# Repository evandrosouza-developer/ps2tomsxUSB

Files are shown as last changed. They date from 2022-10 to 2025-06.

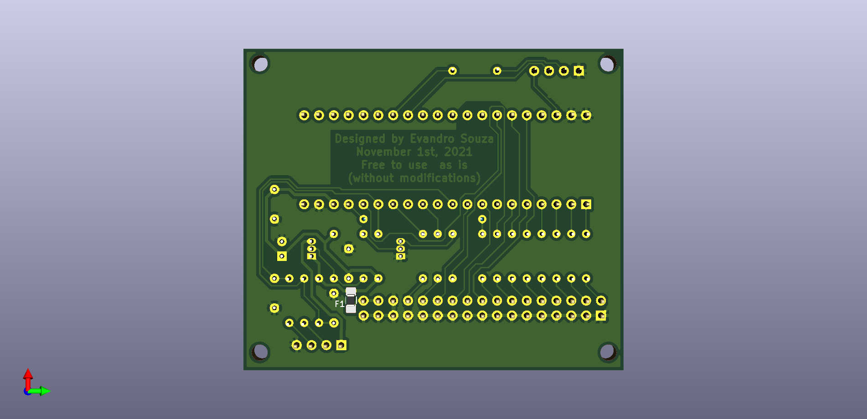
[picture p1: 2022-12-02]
Documentation/Kicad/F1/PS2-MSX-F1 Back View.png

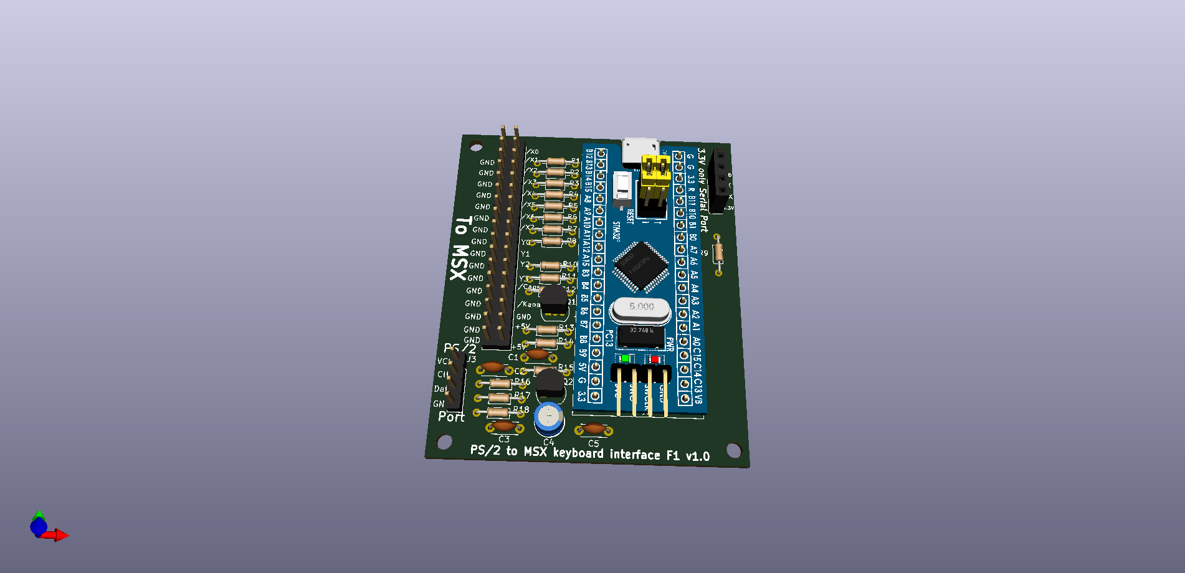
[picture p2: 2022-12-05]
Documentation/Kicad/F1/PS2-MSX-F1 Lower front.png

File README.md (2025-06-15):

# STM32: PS/2 to MSX Keyboard Converter

# Introduction

First of all, to people who use or had used MSX, welcome, bem-vindos, welkom, bienvenidos, добро пожаловать, 환영하다 and ようこそ, to visit my repository.

Instead of an application to this old japanese home computer standards is not so widely useful in nowadays, I made this to learn STM32 hardware and software technics, and I'd like it to be useful and let us back in time and make our MSX computer jewlers work with joyful to our pleasure.

The MSX Keyboard enviroment components (PS/2 to MSX Keyboard Converter, MSX Keyboard subsystem Emulator and the modifyed TIO - A simple terminal) are fully functional and debugged and here I used a lot of concepts that, IMHO could be used as idea sources to your applications.  

# Lets do it!

This interface has the function of connect a PS/2 keyboard (or a USB one in compatibility mode) as source to TTL zero (low state) active matrix based computers, like MSX and ZX-Spectrum as destination. It is meant to connect a keyboard, which only provides a PS/2 connector, to a MSX (or any one that have a up to 15 active columns and reads zeroes througth 8 bits - up to 15 x 8 matrix) computer.  

The differencial of this design is to allow user to customize and do a hot update of the database layout of this PS/2 Keyboard, as like as the MSX one, through an USB (or async serial) interface and a tty terminal on host side.  

The default database mappings for the keyboard layouts are:

- Source (PS/2 keyboard): 275 (ABNT2 layout - Brazilian Technical Norms Association);

- Target: Brazilian Sharp/Epcom Hotbit HB8000 MSX.  

This firmware was made to support both Blue Pill and Black Pill and it is part of the PS/2 to MSX Converter Enviroment, all of them in my github page, that consists:
```
1)The PS/2 to MSX Keyboard Converter itself, which contains:
1.1) The firmware with source files;
1.2) Doxygen full firmware documentation;
1.3) Schematics and PCB design:
1.3.1) Electronics part Schematics with Kicad files;
1.3.2) Single sided PCB layout with Kicad files and complete set of Gerber files;
1.4) The performance tests of this one are inside the PS/2 to MSX Converter Tester folder.

2)The PS/2 to MSX Converter Tester, which contains:
2.1) The firmware with source files;
2.2) Doxygen full firmware documentation;
2.3) Schematics design with Kicad files;
2.4) The performance tests of the PS/2 to MSX Keyboard Converter are located here.

3) Open tool to create/modify the Database (Translation tables to map from PS/2 Scan Codes to MSX Matrix Codes)
in excel, but it has compatible macros to be executed by Libre Office, Open Office and so on.

4) Tini TTY I/O - `tio` (Linux app with source files) to communicate with console and easily allowing the
user to use it with different keyboard layouts and languages.
```
In case of STM32F103C8T6 (Flash 64K RAM 20K) Blue Pill, you have to aplly STM32F103C6T6 (Flash 32K RAM 10K) without change anything else.

In case of Black Pill, the base system is STM32F401CCU6 so, to use a more memory one, just follow the same instructions here.

This firmware powers and has been tested on the following Windows PS/2 keyboards, with brazilian 275 layout:  
- Compaq RT235BTWBR;  
- Clone KE11090749;  
- Clone #09100.  
  
The inspiring code for the PS/2 module, a PS/2 to USB keyboard adapter, was originally developed based on Cherry G80-3000LSMDE.  

# Why not STM32F103C8T6 Blue Pill?

Because Blue Pill has no 5V tolerant pins available to connect PS/2 + MSX + Serial + USB, unlike Black Pill. Even serial (UART) was feasibled using a 3.3V only port.  
Although, this limitation came with a bonus: The need of a cheaper and greater availability 32KB flash MCU: STM32F103C6T6  

# Dependencies

- `libopencm3`
- `arm-none-eabi-gcc`
- `arm-none-eabi-binutils`

If you plan to debug:
- `arm-none-eabi-gdb`
- `stlink + openocd`

Obs.: If you plan to keep only one copy of LibopenCM3 in your computer, I strongly suggest you to setup the variable OPENCM3_DIR in our system enviroment.

# Preparations

After cloning the repository you need to make the following procedure:

Go to libopencm3 you cloned (eg: cd libopencm3) and make it to be useful by typing:

```
cd libopencm3
make TARGETS='stm32/f1 stm32/f4'
```

Go to this ps2-msx-kb-conv (PS/2 to MSX Converter) project folder and assure that you choose the right target MCU in the system.h file line 69, and make, as follows:

With a plain text editor:
```
#define MCU                       STM32F401
or
#define MCU                       STM32F103
```

Save the file, and,  
Create the image file to be sent to the MCU (Micro Controller Unit):

```
make
```
The created image, compiled with the Arm GNU Toolchain 14.2.Rel1 Released: December 10, 2024, on an aarch64 debian bullseye linux computer is created with the following characteristics, according to the choosen MCU:
```
arm-none-eabi-size ps2-msx-kb-convF4.elf
   text	   data	    bss	    dec	    hex	filename
35796	    384	   8436	  44616	   ae48	ps2-msx-kb-convF4.elf

arm-none-eabi-size ps2-msx-kb-convF1.elf
   text	   data	    bss	    dec	    hex	filename
  27152	    352	   2492	  29996	   752c	ps2-msx-kb-convF1.elf

```

# Hardware and Setup

## Hardware and Setup for Blue Pill:

You will obviously need a STM32F103C6T6 or a STM32F103C8T6 (F1 chip). I have used chinese blue pills. The software was made aiming in use of compatible processors, like GD32 for example. 
  
The software was made considering 8.000Mhz oscillator crystal, to clock the STM32 microcontroller chip at 72MHz. I tested with both STM32F103C6T6 and STM32F103C8T6.

The connections are:

1) PS/2 Keyboard:

- Clock Pin PA12 - Connect to PS/2 mini-din 45322 pin 5 throught R16;  
- Data Pin PA9 - Connect to PS/2 mini-din pin 1 throught R18;    
- +5V PS/2 power - Connect collector of Q2 to mini-din pin 4;  
- GND - Connect GNDD (Digital Ground) to mini-din pin 3.

2) MSX computer:

Obs.: You have to access PPI Ports B0 to B7 (Lines X0 to X7), Port C0 to C3 (Y0 to Y3), Port C6 (Caps Lock, pin 11 of DIP package), and for Russian, Arabic, Korean and Japanese Computers (Cyrillic and Kana alphabets), you have to get access to YM2149/AY3-8910 IOB7, pin 6 of DIP package, or, if your MSX is equipped with S1985(MSX-SYSTEM II), you have to have granted access to pins 71 and 72.  
- Y3 - Connect to MSX PPI 8255 Signal PC3 (HB-8000 CI-15 Pin 17 / XP-800 CI-4 Pin 17);  
- Y2 - Connect to MSX PPI 8255 Signal PC2 (HB-8000 CI-15 Pin 16 / XP-800 CI-4 Pin 16);  
- Y1 - Connect to MSX PPI 8255 Signal PC1 (HB-8000 CI-15 Pin 15 / XP-800 CI-4 Pin 15);  
- Y0 - Connect to MSX PPI 8255 Signal PC0 (HB-8000 CI-15 Pin 14 / XP-800 CI-4 Pin 14);  
- X7 - Connect to MSX PPI 8255 Signal PB7 (HB-8000 CI-15 Pin 25 / XP-800 CI-4 Pin 25);  
- X6 - Connect to MSX PPI 8255 Signal PB6 (HB-8000 CI-15 Pin 24 / XP-800 CI-4 Pin 24);  
- X5 - Connect to MSX PPI 8255 Signal PB5 (HB-8000 CI-15 Pin 23 / XP-800 CI-4 Pin 23);  
- X4 - Connect to MSX PPI 8255 Signal PB4 (HB-8000 CI-15 Pin 22 / XP-800 CI-4 Pin 22);  
- X3 - Connect to MSX PPI 8255 Signal PB3 (HB-8000 CI-15 Pin 21 / XP-800 CI-4 Pin 21);  
- X2 - Connect to MSX PPI 8255 Signal PB2 (HB-8000 CI-15 Pin 20 / XP-800 CI-4 Pin 20);  
- X1 - Connect to MSX PPI 8255 Signal PB1 (HB-8000 CI-15 Pin 19 / XP-800 CI-4 Pin 19);  
- X0 - Connect to MSX PPI 8255 Signal PB0 (HB-8000 CI-15 Pin 18 / XP-800 CI-4 Pin 18);  
- Caps LED - Connect to MSX PPI 8255 Signal PC6 (HB-8000 CI-15 Pin 11 / XP-800 CI-4 Pin 11) or S1985 Pin 71;  
- Kana LED - Connect to MSX YM2149 or AY3-8910 IOB7, pin 6 of DIP package or S1985 Pin 72. If the MSX doesn't have this indicator LED, you can leave it open, as it already has an internal pull-up connection. In brazilian, argentinian and most european MSX, for example, this is a non-connect pin.   

3) Serial console:
 It is the only option for console available if you are using Blue Pill. See "Why not STM32F103C8T6 Blue Pill?".

  The connection is needed only to update internal PS/2 to MSX key mapping Database.  
  Config: 115200, 8, n, 1 (115200 bps, 8 bits, no parity, 1 stop bit);  
  Tx: A2  
  Rx: A3  

  *******************************************************************************************************

  Obs.: It is a only 3.3V port, compatible to TTL levels, so do NOT use it with "1" level higher than 3.3V!!

  *******************************************************************************************************

 About physical connection: The connection has to be done with TX of your host system connected with RX of the PS/2 to MSX Keyboard Converter (device), and the device's TX has to be connected to host's RX.

## Hardware and Setup for Black Pill:

You will obviously need a a F4 chip (STM32F401CCU6 or up, if using WeAct Mini F4 compatible black pill).

The software was made considering 25.000Mhz oscillator crystal, to clock the STM32 microcontroller chip at 84MHz. I tested with both STM32F401CCU6 and STM32F401CDU6.

The connections are:

1) PS/2 Keyboard (J3- PS/2 Port) :

- PS/2 power - Pin 1 - Connect to PS/2 mini-din 45322 pin 4;  
- Clock      - Pin 2 - Connect to PS/2 mini-din 45322 pin 5;  
- Data       - Pin 3 - Connect to PS/2 mini-din 45322 pin 1;  
- GNDD       - Pin 4 - Connect to PS/2 mini-din 45322 pin 3.  

2) MSX computer:

Obs.: You have to access PPI Ports B0 to B7 (Lines X0 to X7), Port C0 to C3 (Y0 to Y3), Port C6 (Caps Lock, pin 11 of DIP package), and for Russian and Japanese Computers (Cyrillic and Kana alphabets), you have to get access to YM2149/AY3-8910 IOB7, pin 6 of DIP package, or, if your MSX is equipped with S1985(MSX-SYSTEM II), you have to have granted access to pins 71 and 72.  

- Y3 - Connect to MSX PPI 8255 Signal PC3 (HB-8000 CI-15 Pin 17 / XP-800 CI-4 Pin 17);  
- Y2 - Connect to MSX PPI 8255 Signal PC2 (HB-8000 CI-15 Pin 16 / XP-800 CI-4 Pin 16);  
- Y1 - Connect to MSX PPI 8255 Signal PC1 (HB-8000 CI-15 Pin 15 / XP-800 CI-4 Pin 15);  
- Y0 - Connect to MSX PPI 8255 Signal PC0 (HB-8000 CI-15 Pin 14 / XP-800 CI-4 Pin 14);  
- X7 - Connect to MSX PPI 8255 Signal PB7 (HB-8000 CI-15 Pin 25 / XP-800 CI-4 Pin 25);  
- X6 - Connect to MSX PPI 8255 Signal PB6 (HB-8000 CI-15 Pin 24 / XP-800 CI-4 Pin 24);  
- X5 - Connect to MSX PPI 8255 Signal PB5 (HB-8000 CI-15 Pin 23 / XP-800 CI-4 Pin 23);  
- X4 - Connect to MSX PPI 8255 Signal PB4 (HB-8000 CI-15 Pin 22 / XP-800 CI-4 Pin 22);  
- X3 - Connect to MSX PPI 8255 Signal PB3 (HB-8000 CI-15 Pin 21 / XP-800 CI-4 Pin 21);  
- X2 - Connect to MSX PPI 8255 Signal PB2 (HB-8000 CI-15 Pin 20 / XP-800 CI-4 Pin 20);  
- X1 - Connect to MSX PPI 8255 Signal PB1 (HB-8000 CI-15 Pin 19 / XP-800 CI-4 Pin 19);  
- X0 - Connect to MSX PPI 8255 Signal PB0 (HB-8000 CI-15 Pin 18 / XP-800 CI-4 Pin 18);  
- Caps LED - Connect to MSX PPI 8255 Signal PC6 (HB-8000 CI-15 Pin 11 / XP-800 CI-4 Pin 11) or S1985 Pin 71;  
- Kana LED - Connect to MSX YM2149 or AY3-8910 IOB7, pin 6 of DIP package or S1985 Pin 72. If the MSX doesn't have this indicator LED, you can leave it open, as it already has an internal pull-up connection. In brazilian, argentinian and most european MSX, for example, this is a non-connect pin.   
  
3) USB Type C: Needed only to update internal PS/2 to MSX key mapping Database. To create this Intel Hex file, better to use the Macro based Excel file, so you have to trust and enable macro excecution in excel app. The USB cable is the same as you use with yor mobile phone (USB Type-A Male x USB Type C Male).  
  
4) Serial console: Same observations of USB are applicable here, with exception of the cable itself. Here the connection has to be done with TX of your host system connected with RX of the PS/2 to MSX Keyboard Converter (device), and the device's TX has to be connected to host's RX.  
   Config: 115200, 8, n, 1 (115200 bps, 8 bits, no parity, 1 stop bit);  
   Tx: A9  
   Rx: A10  

  *******************************************************************************************************

  Obs.: It uses a 5V tolerant port, which is compatible to TTL levels, so do NOT use it with "1" level higher than 5V!!

  *******************************************************************************************************  

# The Database structure: Keyboard from/to mapping

This design was developed to connect, as default, an ABNT-2 brazilian PC keyboard to the brazilian MSX Sharp/Epcom HB-8000, but it is very easy to apply a hot change of its mapping:

- You have to compile and upload this new database to the Converter. This task is easily managed with the help of a Database compiler: The macro enabled excel file named `PS2toMSX_Database_Compiler.xlsm`.

To edit and compile the Database file, both source and target keyboard layouts, I prepaired a dedicated "key assembler in excel", so I can boldly recommend you to use the excel file `PS2toMSX_Database_Compiler.xlsm` available at github page.  
The Database Compiler file has 3 sheets: One for HB-8000, the second as XP-800 and the third one as an International MSX. Unfortunately, the last one was not tested. Just fillin the table, click on the keyboard image of upper left of the current sheet and wait for VBA has been concluded.  
The Database Compiler excel file exports the IHD.hex file (Intel Hex Database) to be hot applyed to PS/2 to MSX Keyboard Converter's Console, when this one boots up with no PS/2 Keyboard pluged in. Just follow console instructions. You may use `tio` as a terminal linux app to upload it.  
 
*******************************************************************  
<div align= "center"><strong>IMPORTANT</strong>  </div> 
<div align="left">If you are using Blackpill board and are uploading Database through USB, please do a FULL DISCONNECT (ALL lines INCUDING POWER) from MSX,  to avoid short circuit through power supply lines!  

I strongly suggest that the Black Pill board be pulled out from PS/2 to MSX Keyboard Converter board, as the power is going to be supplyed from USB and the heavy task to reconnect all will be saved, if you decided not to use the connector on the J1, which would simplify and make the task much safer.

*******************************************************************  

## Technical details about the Database structure

	There are 320 lines, so this structure is capable of manage up to 159 PS/2 keys, each key with make and break codes.

	The first and last lines are reserved for control (Database version, Database unavailable: seek next, double consistensy check, among others);
	
	On the first line there are information related to this Database version:
	- Bytes 0, 1 and 2: Database version ("0x01", "0x00", "0xFF")
	- Byte 3: Mapped function. Description:  
	  |  (bits 7-6): Reserved - keep it at high state;  
	  |  (bit 5): default value of enable_xon_xoff (true to enable it);  
	  |  (bit 4): default value of ps2numlockstate at power up (true to enable it);  
	  |  (bits 3-0): y_dummy (non valid colunm) - default value is 15 (0b1111);  
	- Bytes 4-7: Reserved - Keep it as 0xFFFFFFFF;
        When this copy of the Database is let unavailable, the first line becomes ("0x00", "0x00", "0x00", "0x00", "0x01", "0x02", 
	"0x04", "0x08"), meaning to seek the next one.

	On the line 319 (the last one) there are information related to this Database integrity:  
	- Bytes 0-5: Reserved - Keep each byte as 0xFF;  
	- Byte 6: CheckSum (Integrity);  
	- Byte 7: bcc (a vertical parity used for integrity);  

	Line 1 starts the raw of the Database:  
  
	The three first columns of each line are the mapped PS/2 scan codes;  
  
	The 4th column is The Control Byte, detailed bellow:   
	CONTROL BYTE:  
	- High nibble is Reserved;  
	- (bit 3) Combined Shift;  
	- (bit 2) Reserved-Not used;  
	- (bits 1-0) Modifyer Type:  
	  |		0 - Default mapping  
	  |		1 - NumLock Status+Shift changes  
	  |		2 - PS/2 Shift  
	  |		3 - Reserved-Not used  

	This table has 3 modifyers: Up two MSX keys are considered to each mapping behavior modifying:
	- 5th and 6th columns have the mapping 0 - "Default mapping";  
	- 7th and 8th columns share mappings:  1 and 2:  
	  |                                    1 - "NumLock Status+Shift changes";  
	  |                                    2 - "PS/2 Shift", where I need to release the sinalized Shift in PS/2 to the MSX and put the code key, and so, release them, reapplying the Shift key, deppending on the initial state;  

	Each column has a MSX encoded key, with the following structure:
	- (bits 7-4) MSX Y PPI 8255 PC3-0 is sent to a BCD decoder with OC outputs, for example:  
	  |	In the case of Hotbit HB8000, the keyboard scan is done as a 9 columns scan, CI-16 7445N 08 to 00;  
	  |	If equals to value stored at bits 3-0 of byte 3 of the Database file, there is no MSX key mapped.  
	- (bit 3) => 0: keypress / 1: key release;             
	- (bits 2-0) MSX X, ie, which bit of the PPI 8255 PB7-0 will carry information of bit 3 (keypress/key release).  

# Download your code to hardware

Use a ST-Link v2 Programmer (or similar), Black Magic Probe or another Serial Wire supported tool to flash the program using `make flash` onto the STM32.

If you choose a Black Pill, even you don't have plans to develop, you earn a bonus: you will not have the need of a dedicated programmer like ST-Link, J-link or Black Magic Probe to download your code, as STM32F4x1 MiniF4 already comes with DFU (Device Firmware Upgrade) available in the system ROM to do so through USB. So, on linux, just follow these steps:

1) Unplug the MSX connection or take off the Black Pill from the PS/2 to MSX Converter Main Board;  
2) Install dfu-util. This example is for Debian derivated Linux (Debian, Ubuntu, Mint, etc):
`sudo apt install dfu-util`  
3) Make sure the chip is at least 25°C (you may let it working for a while and help with the heat of your finger), because it uses internal oscillator to clock USB, factory trimmed to 25°C;  
4) Plug the USB cable to your computer and the STM32F4 board while holding both NRST and BOOT0;  
5) Then release BOOT0 AFTER 0.5 second you released NRST;  
6) Now you can see a new USB device in your linux enviroment, through `lsusb` command: 0483:df11. Run the command to flash the code itself:
`dfu-util -d 0483:df11 -a 0 -s 0x08000000 -D ps2-msx-kb-convF4.bin`  
7) Unplug the USB cable, undo the step 1 and power on the device to run the code.  
  
On windows you can download STM32CubeProg on ST site, replacing step 2. You have to adjust step 6 to this tool. Please follow ST instructions.

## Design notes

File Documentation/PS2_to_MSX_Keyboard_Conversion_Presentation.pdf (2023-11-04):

PPT模板下载：www.1ppt.com/moban/ 行业PPT模板：www.1ppt.com/hangye/ 节日PPT模板：www.1ppt.com/jieri/ PPT素材下载：www.1ppt.com/sucai/ PPT背景图片：www.1ppt.com/beijing/ PPT图表下载：www.1ppt.com/tubiao/
优秀PPT下载：www.1ppt.com/xiazai/ | PPT教程： www.1ppt.com/powerpoint/
Word教程： www.1ppt.com/word/ | Excel教程：www.1ppt.com/excel/
资料下载：www.1ppt.com/ziliao/
PPT课件下载：www.1ppt.com/kejian/
范文下载：www.1ppt.com/fanwen/

# PS/2 Keyboard for MSX And Legacy computers

## Evandro Souza <evandro.r.souza@gmail.com

## Based on: . ARM Cortex M3 Blue Pill stm32f103c6t6 . ARM Cortex M4 Black Pill stm32f401ccu6

# Introduction

## The main objective was to learn to use the ARM Core M3 and M4 Open Develop

Enviroment (free EDA, software tools and libraries).

## To do so, I chose a critic mission challenge, with implementation features not

## available in various smart solutions, as an example, the update translation

## database tables are not possible without full firmware recompilation and upload

## to hardware. In this one, a new database can be assembled and easily hot

upgradeable by the user through USB or serial port any times the user needs it.

## Show up a complete product design with full open documentation: Hardware

## (schematics plus PCB with gerber files, to ordering from PCB manufacturers) &

## Software (sources and its documentation), in order to allow to put this one into

production and get it maintained and supported.

Show up a simple and low cost solution to implement.

# Index

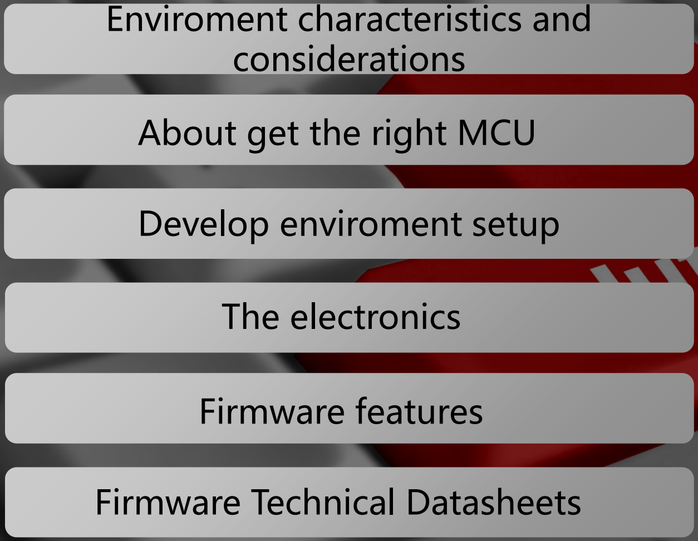
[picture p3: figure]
Enviroment characteristics and considerations; About get the right MCU; Develop enviroment setup; The electronics; Firmware features; Firmware Technical Datasheets

# Now

# Enviroment characteristics and

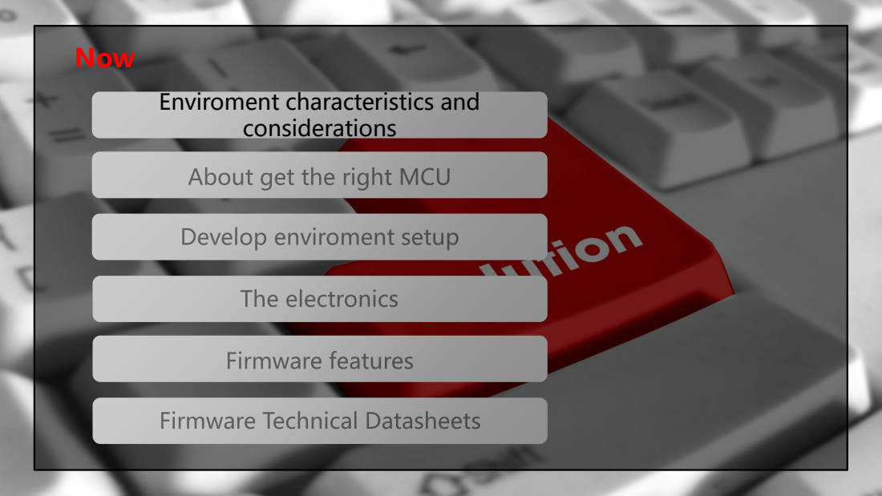
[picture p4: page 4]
considerations

# How MSX works (1/2)

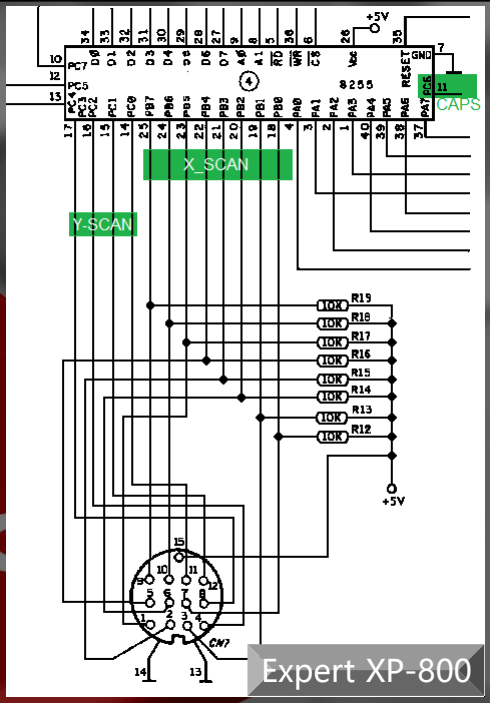
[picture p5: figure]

The MSX keyboard is a 8 lines (X) by up to 15 colunms (Y) matrix, which can achieve a theoretical maximum of 120 keys – The HB8000 has 9 columns, as seen on the example (J25 is the keyboard conector and, on left, its key mapping table). A highend japanese MSX uses a 11 colunms keyboard;
Firstly, the scan is done by writing on Y3:0 (PC3:0, address 0AAH), which goes to a decoder (up to) 4x16 with open-collector outputs, and reading from X7:0 (through PPI 8255 PB7:0, port 0A9H); The Caps Lock and Katakana states (“0”active ) are sampled directly from MSX hardware and echoed on PS/2 keyboard LEDs.
Sharp HB-8000 | Expert XP-800 X_SCAN Y_SCAN | CAPS

# How MSX works (2/2)

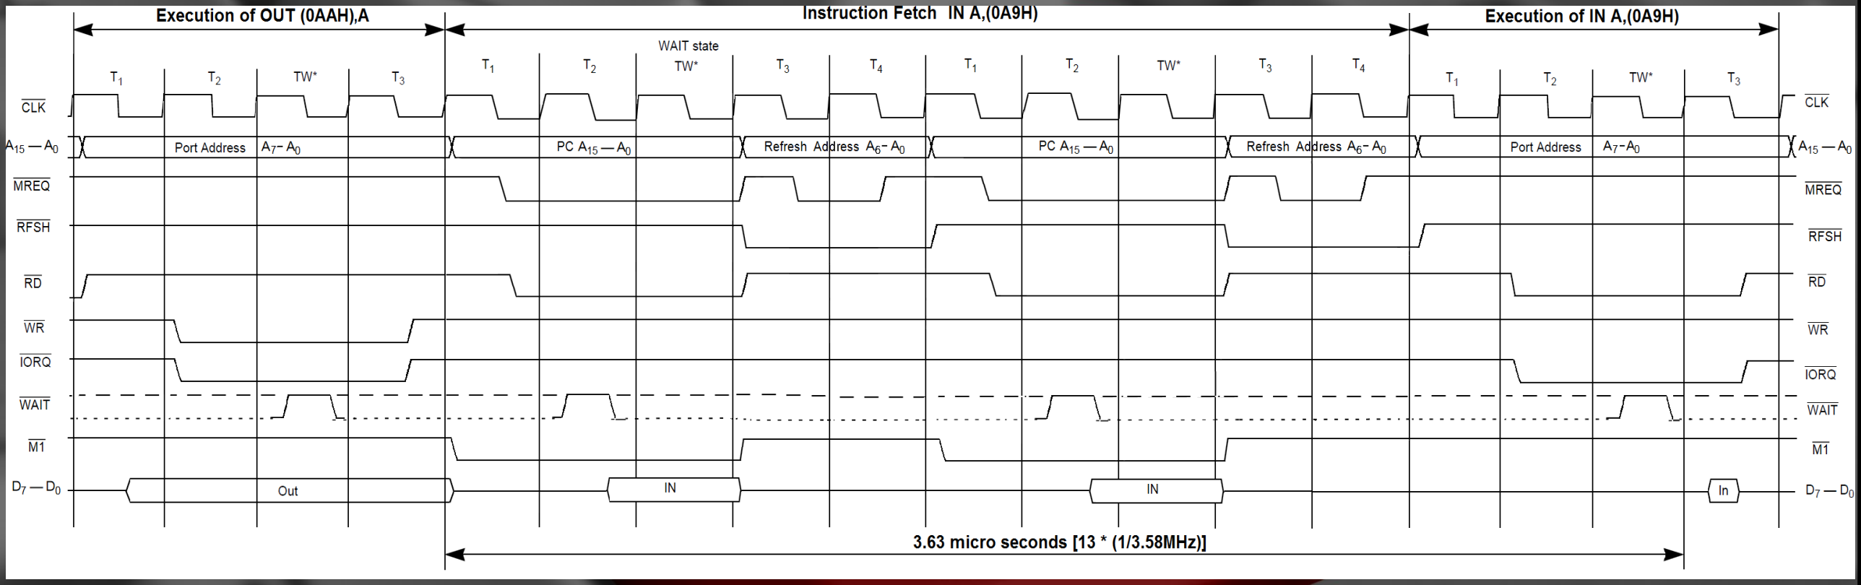
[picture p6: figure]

Detailed timming diagram of a MSX Keyboard read (OUT followed by an IN) The available amount of time after the Y update (execution of OUT (0AAH), A) is aproximately 3,6µs;
- Obs.: In special circunstancies, the keyboard reading (IN A, 0A9H) is not done just after OUT (eg: games), so, the converter must update X as soon as the PS/2 Keyboard events occur, according to respective Y of the moment. In other words, the converter must keep updating X even if the MSX is not doing the keyboard scan.

# PS/2 Keyboard - Timmings

The PS/2 keyboard communicates to host computer through a half duplex syncronous serial line with 2 wires, in a unbalanced (gnd is the return path) communication mode. Two lines are used: Data and Clock;
- The clock rate is in range from 10K to 16,7KHz;
Observe the following timming diagrams of:
1) From PS/2 Keyboard to host (PC or converter):

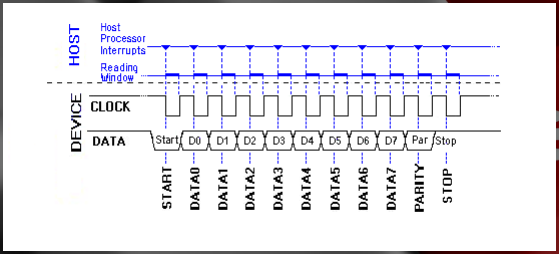
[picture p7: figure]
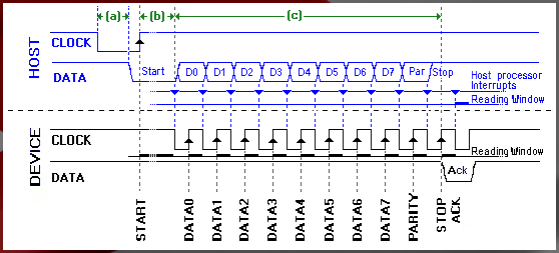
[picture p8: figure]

- (a) Host forces the clock line to low (0) for at least 100µs;
- (b) Is the time that keyboard requires to start to send clock to receive the frame, which can take up to 15ms;
- (c) Is the time to conclude the frame reception, after the keyboard has started the clock sending, and must by up to 2ms;
2) From host to keyboard:

# PS/2 Keyboard - Layout

- There are many exclusive MSX keys, like Graph, Code, Select and Stop. That though is also valid for a PC keyboard;
- The scan codes do not have have any pairing (relationships) with keytops mark;
- The scan codes have different sizes: from 1 to 8 bytes;
- The PS/2 keyboard sends Type 2 codes (AT type) to the host and the auto-repeat is only on the last one pressed;
- The scan codes are not dependent of physical layout – For example: The codes 0x51 (key “/” on the left side of right Shift) and 0x6D (Key “.” of numeric keypad) are exclusive of ABNT2 (Id=275) keyboards;
- Here is the example of the base keyboard to todo this development (ABNT2 keyboard) with make scan codes:

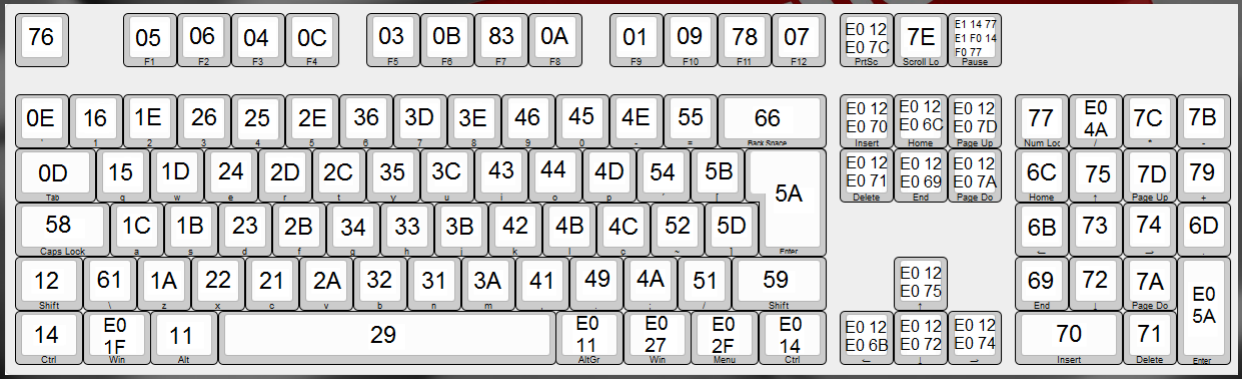
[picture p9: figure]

# Now

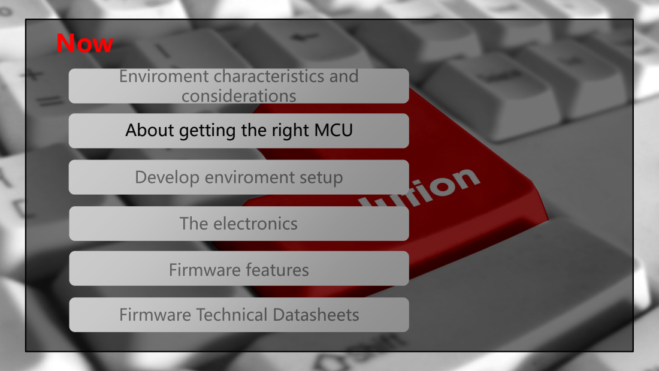
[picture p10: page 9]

About getting the right MCU

# Picking the MCU (Micro Controller Unit)

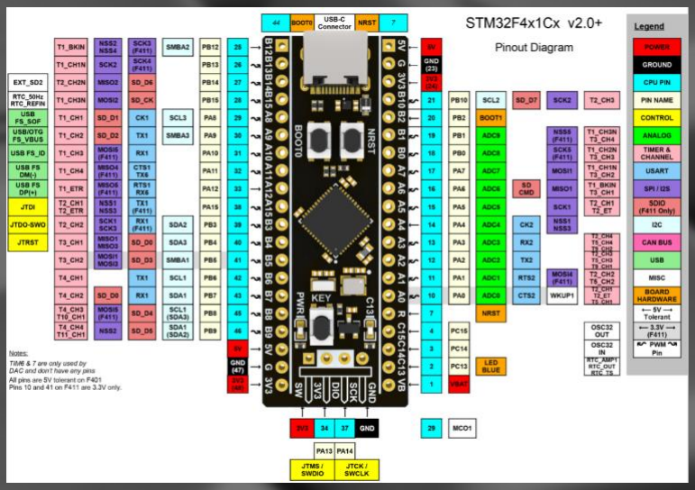
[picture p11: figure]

## Features met

1. Low power consumption;
2. At least 16 pins must be 5V tolerant;
3. Output pins must support be configured as OD (Open Drain);
4. OD pins must allow to get their state read at any time;
5. At least 5 pins must be enabled as external interrupt;
6. The external interrupt pins connected to Y_SCAN must not share

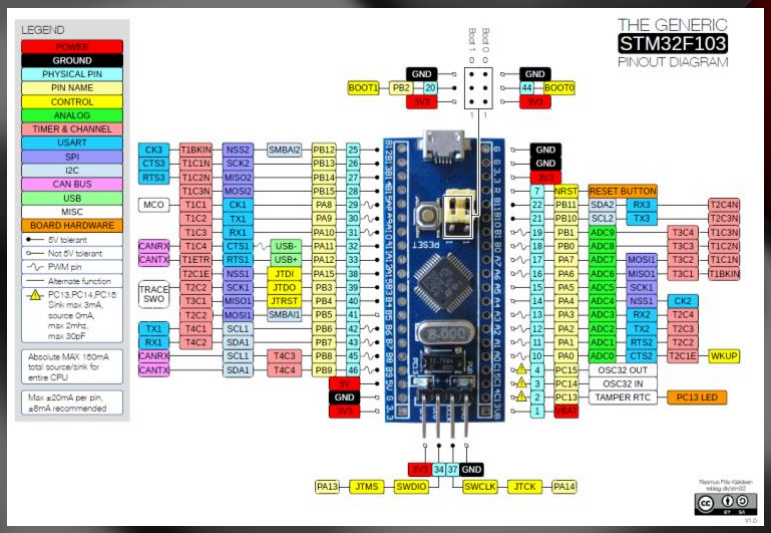
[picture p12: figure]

interrupt resourses;
7. Its non volatile memory must be grather than 2560 bytes and must be writeable by software;

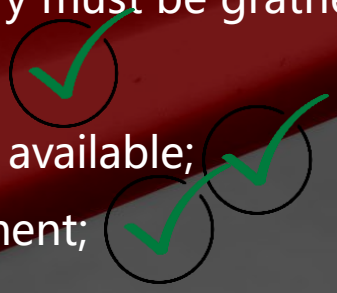
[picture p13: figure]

8. Plenty documentation available;
9. Open develop enviroment;
10. Low cost;
11. Easy to get.

# Now

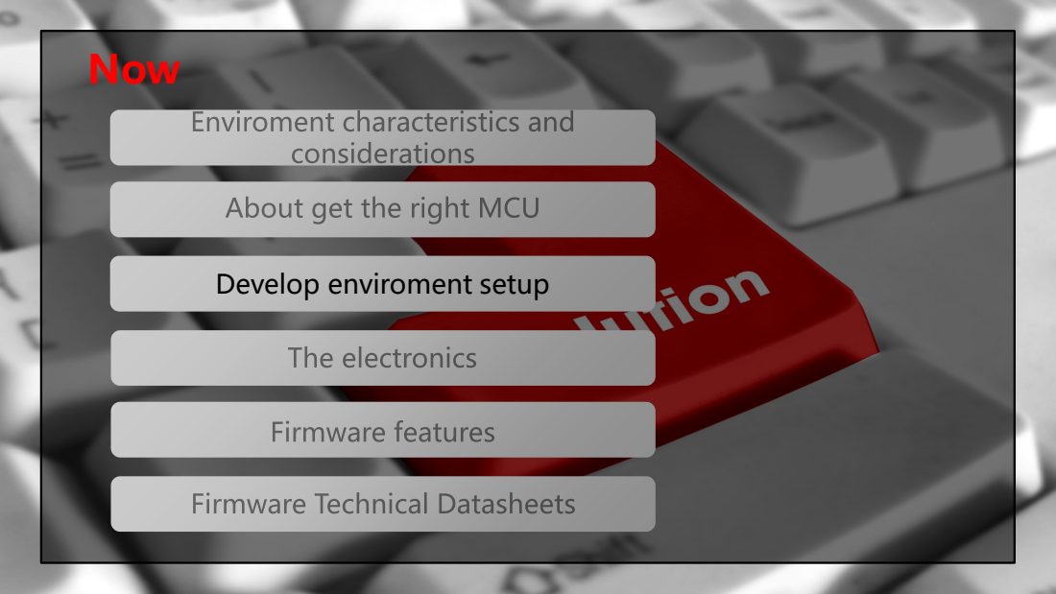
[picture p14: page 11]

Develop enviroment setup

# Develop Enviroment Setup

Linux Ubuntu 22.04 | ARM GCC Tools | LibOpenCM3 | OpenOCD | Visual Studio Code
Debian Linux 11 | ARM GCC Tools | LibOpenCM3 | Black Magic Probe | Visual Studio Code

AMD x64

ARM aarch64

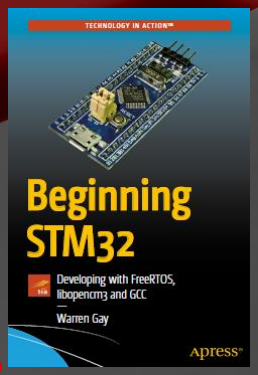
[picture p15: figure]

The first steps was done with the orientation of this remarkable book:
Warren Gay, Beginning STM32 Developing with FreeRTOS, libopencm3 and GCC,
which | was | introduced | me | by | Ismael | Lopes | da | Silva, | site
https://www.embarcados.com.br/serie/programacao-com-a-placa-blue-pill/, | to
whom I am very grateful to his excellent level of didactic and evaluation article!

# Now

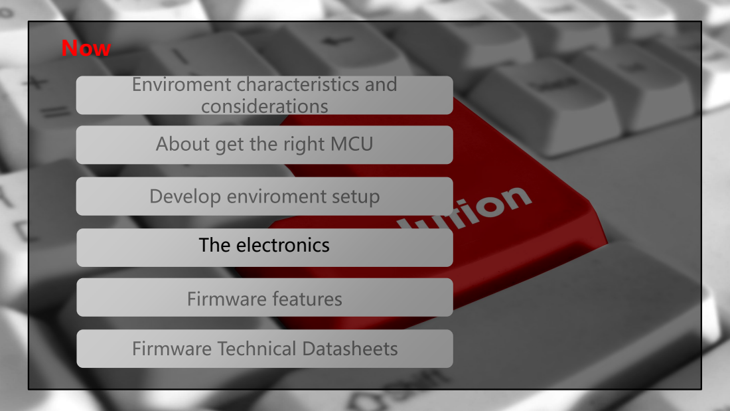
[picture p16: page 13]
The electronics

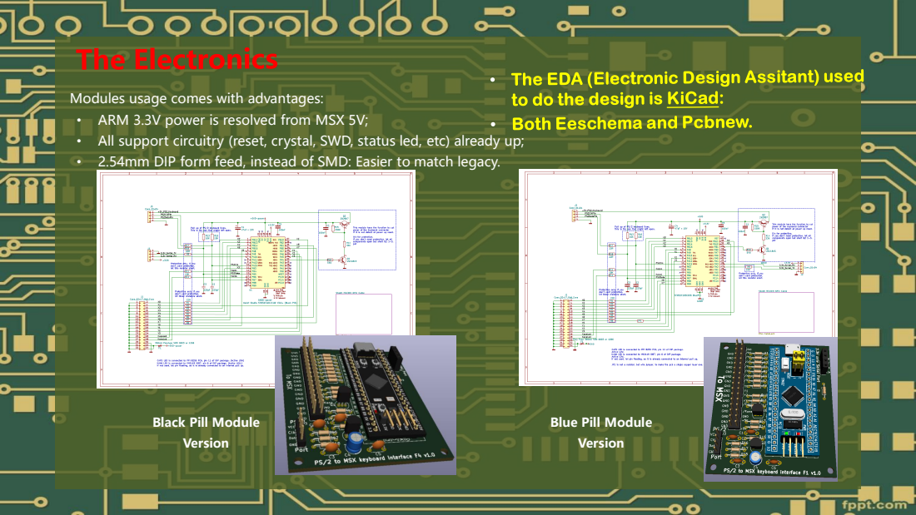
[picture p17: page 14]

Modules usage comes with advantages:
• ARM 3.3V power is resolved from MSX 5V;
• All support circuitry (reset, crystal, SWD, status led, etc) already up;
• 2.54mm DIP form feed, instead of SMD: Easier to match legacy.

Black Pill Module
Version

Blue Pill Module

# The electronics with Black Pill module

- 100% of external electronics has the function of protecting the PS/2 Keyboard, ARM module and MSX host;

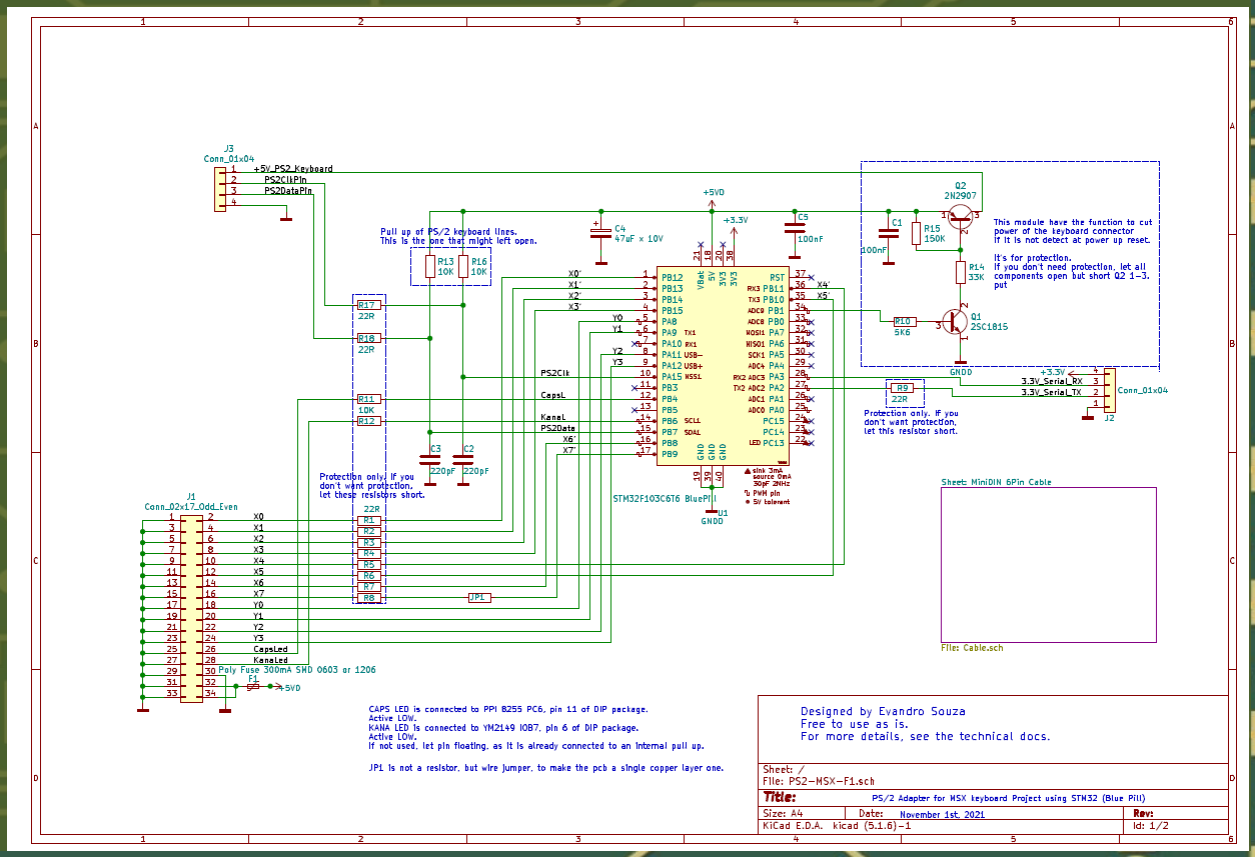
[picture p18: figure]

- Powers down the PS/2 interface when
keyboard is not detected while booting-up;
- C2 and C3 (the capacitors in parallel with PS2Clk and PS2Data) absorv switching spikes, minimizing false detections of PS/2 changes;
- The mesasured consumption with black pill module was 28mA @ 5V;
- Dimension of single layer PCB: 65 x 55mm;
- BlackPill has USB capabilities and in this design USB devices are configured;
- Both the USB and USART Port are 5V tolerant so, do not worry to integrate to 5V support circuitry.

# The electronics with Blue Pill module

- Blue Pill has the same basic specifications as Black Pill, but does not have USB implemented. This reduced the code size, so I choose a cheaper MCU: stm32f103c6t6 (32K Flash 10K RAM).

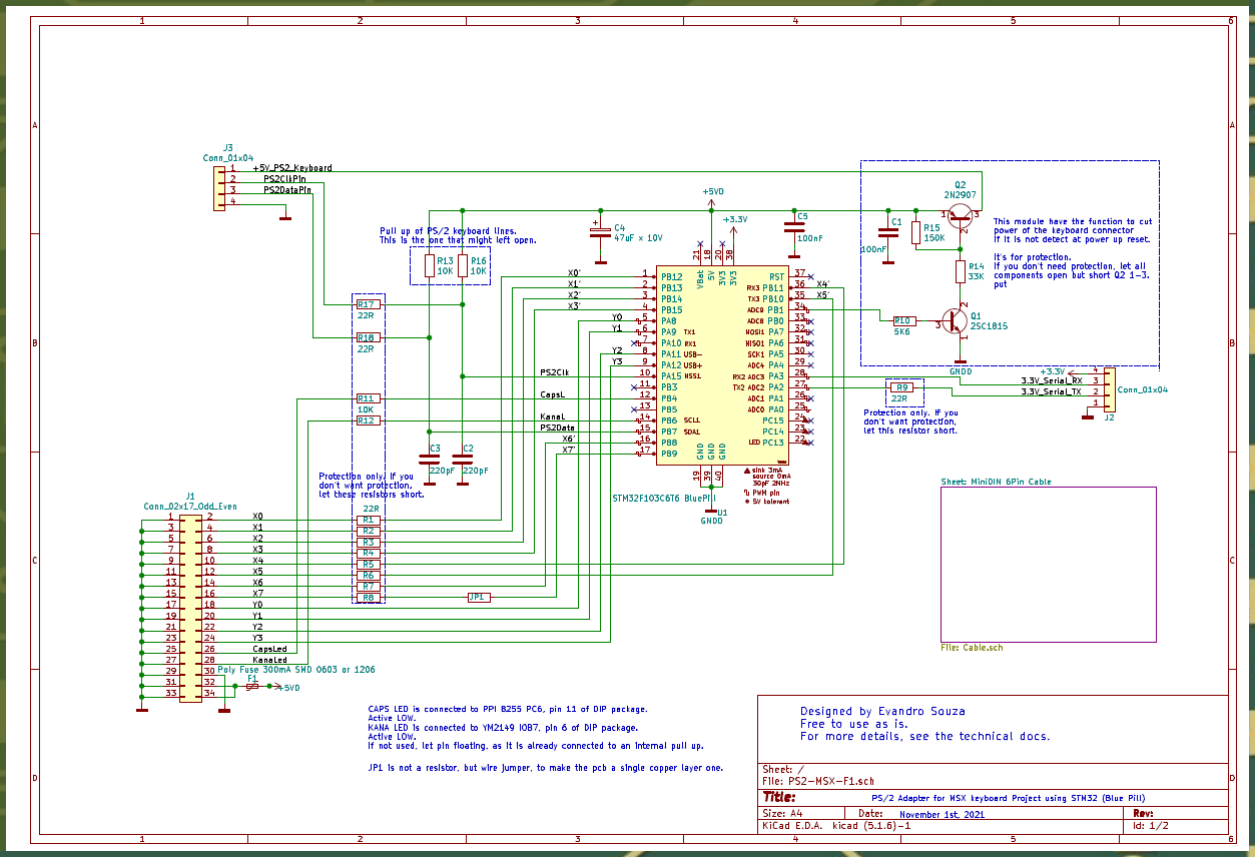
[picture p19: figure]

- Although BluePill has USB capabilities,
there is no sufficient resources (5V
tolerant pins) to feasible USB. Even to
UART I have to use 3.3V pins (no 5V tolerant ones are available).

# Now

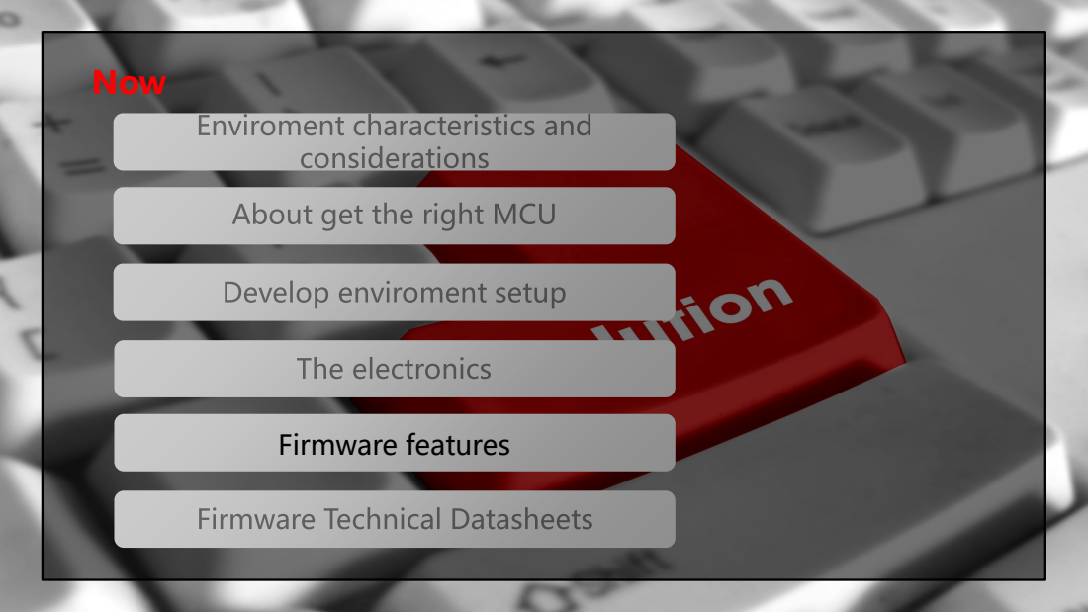
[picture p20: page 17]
Firmware features

# Firmware features

The Database (PS/2 to MSX translation instructions) may be changed at any time: You have only to get a new Database, connect a tty terminal capable to send ASCII files and connect this terminal to the PS/2 to MSX Converter console, through an USB or a serial port. Unplug the keyboard and turn on the Converter.

The Database (an Intel Hex text file) is updated via console, with a help of a tty program (eg TIO) , that will guide you through the steps => A 15 seconds operation.

The Converter controls NumLock as PC does, and CapsLock and Scroll Lock leds, this last one mapped from Katakana (or Cyrilic or Korean) indicator, are sampled directly from MSX hardware. It echoes real time state changes.

The MSX puts colunm (Y_Scan) and the converter answers with line pointed (X_Scan) by Y_Scan. If there are no Y_Scan changes, this Converter will update X_Scan PS/2 Keyboard events related to that Y_Scan.

The valid PS/2 events for the Converter are only make and break. As auto repeat has no sense for Converter firmware, it has been kept as low as possible: Autorepeat start delay is initalized as 1.0s and repeat rate as 2CPS.

Due to the easy Database upload, the user is empowered to rebuild new one and upload anytime how this converter will act.

# Now

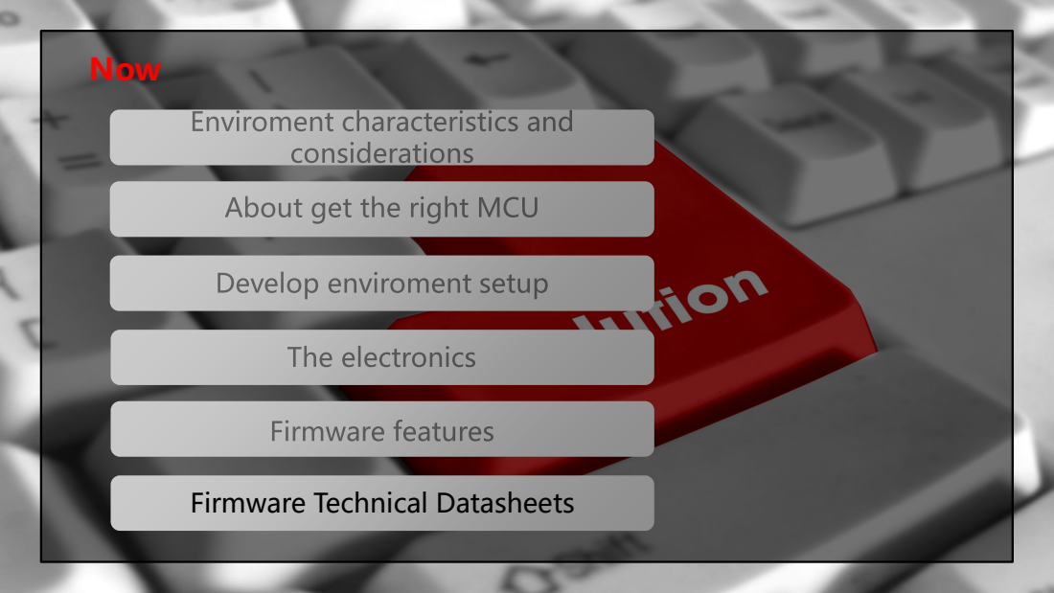
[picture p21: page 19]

Firmware Technical Datasheets

# Firmware Technical Data

## The phylosofy used is to to a Bare metal programming, it

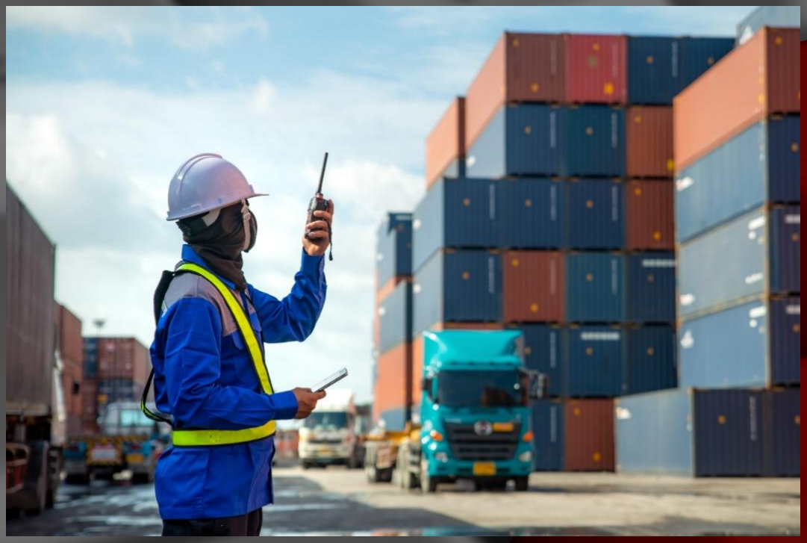
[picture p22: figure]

means no use of any Operating System or RTOS.

## The used languages are C++ and C, to make all firmware

## and TIO. The other language used was Microsoft Office

VBA (to create/manage Database).

## Task allocation here is used and implemented by hardware

interruptions, trigging: MSX Y-Scan, PS/2 keyboard, USART, USB, DMA, 30Hz System timer & 1µs resolution Timer.

- The complete source code with Doxygen documentation, open excel Database compiler, schematics, pcb and

its gerber files are all availabe at my github repository: https://github.com/evandrosouza-developer/ps2tomsxUSB;

- Other designs of this ecosystem: MSX Keyboard Emulator https://github.com/evandrosouza-developer/Tester-ps2-msx and

TIO (Tiny Terminal application) https://github.com/evandrosouza-developer/tio-v2.5a.

# THANKS

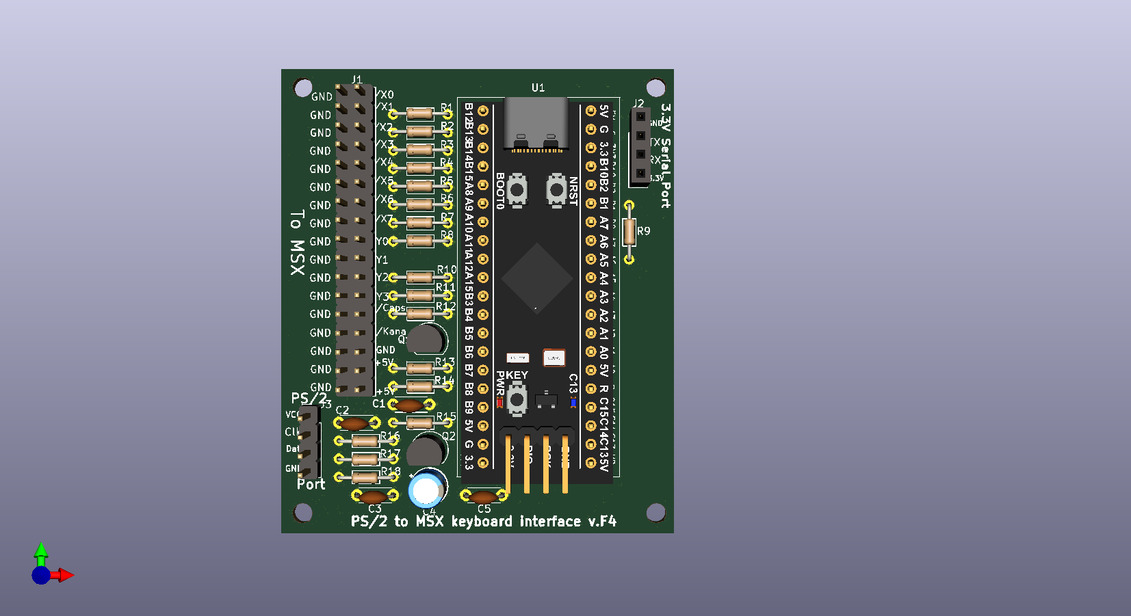
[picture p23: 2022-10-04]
Documentation/Kicad/F4/PS2-MSX-F4_Front_view.png

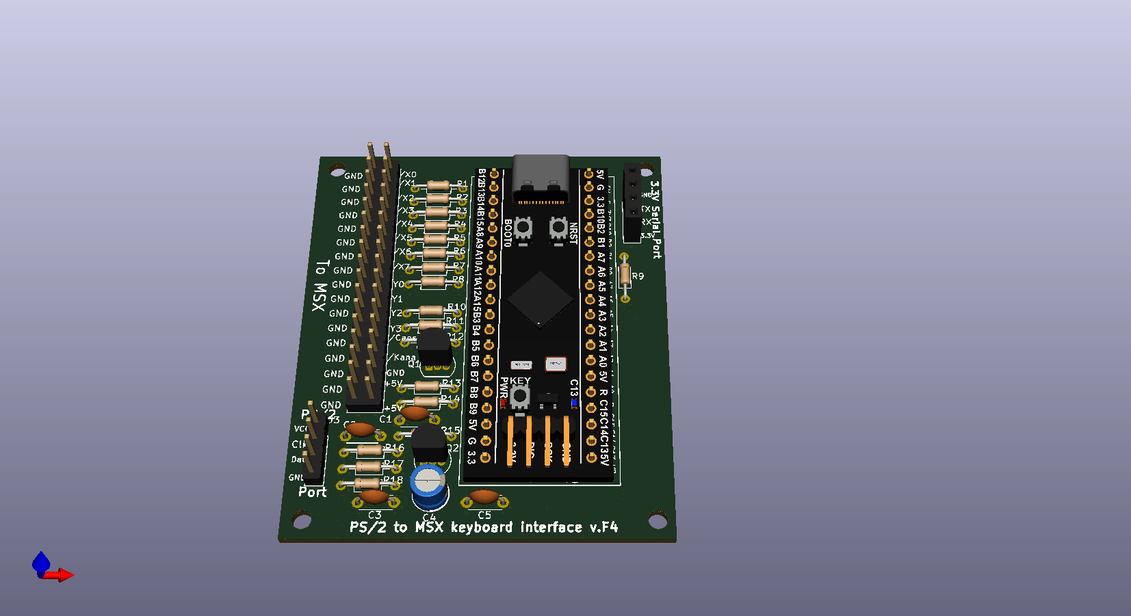
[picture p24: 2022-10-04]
Documentation/Kicad/F4/PS2-MSX-F4 Button view.png

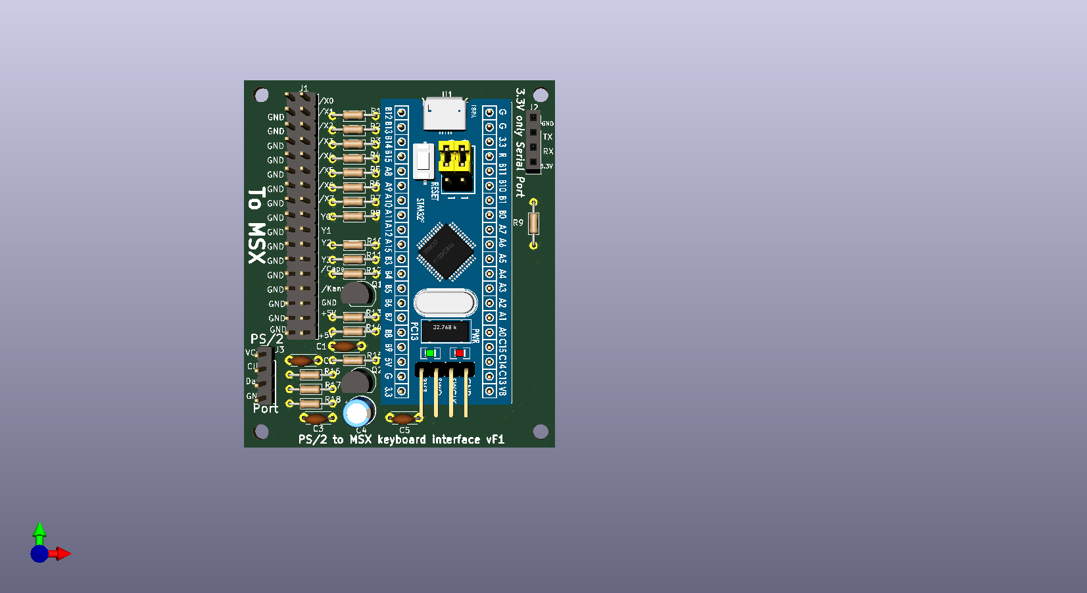
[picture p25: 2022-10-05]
Documentation/Kicad/F1/PS2-MSX-F1_Front_View.png

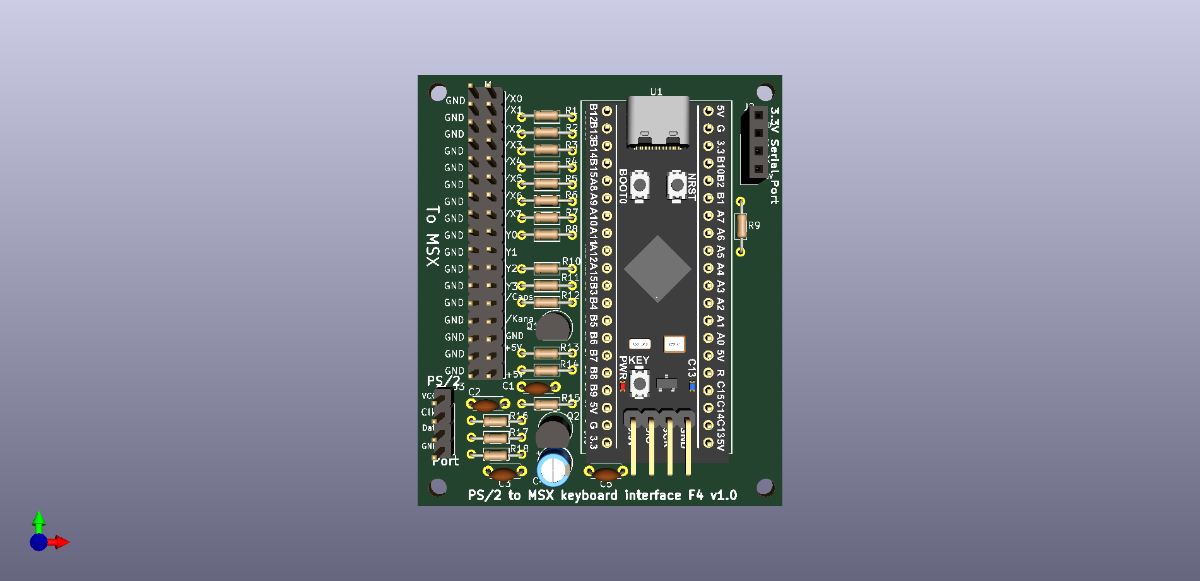
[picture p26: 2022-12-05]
Documentation/Kicad/F4/PS2-MSX-F4 Front view.png

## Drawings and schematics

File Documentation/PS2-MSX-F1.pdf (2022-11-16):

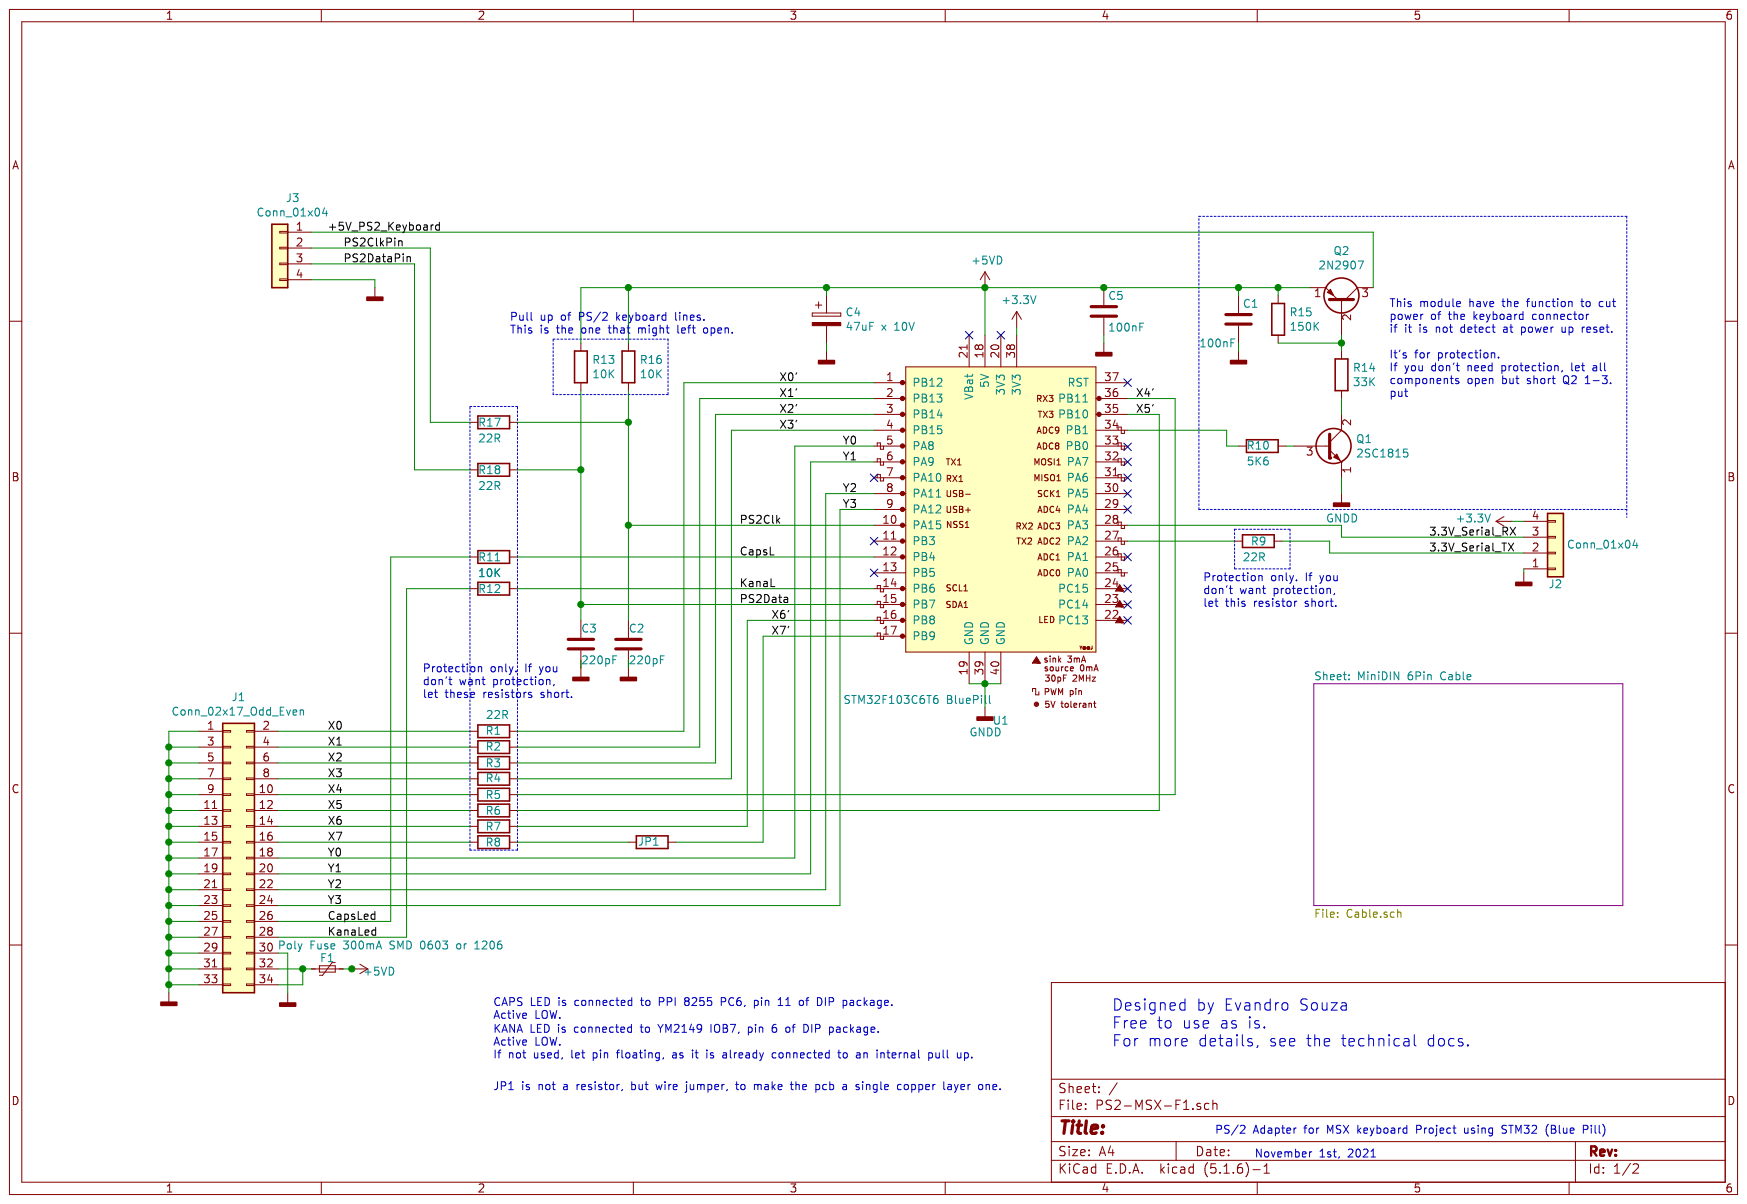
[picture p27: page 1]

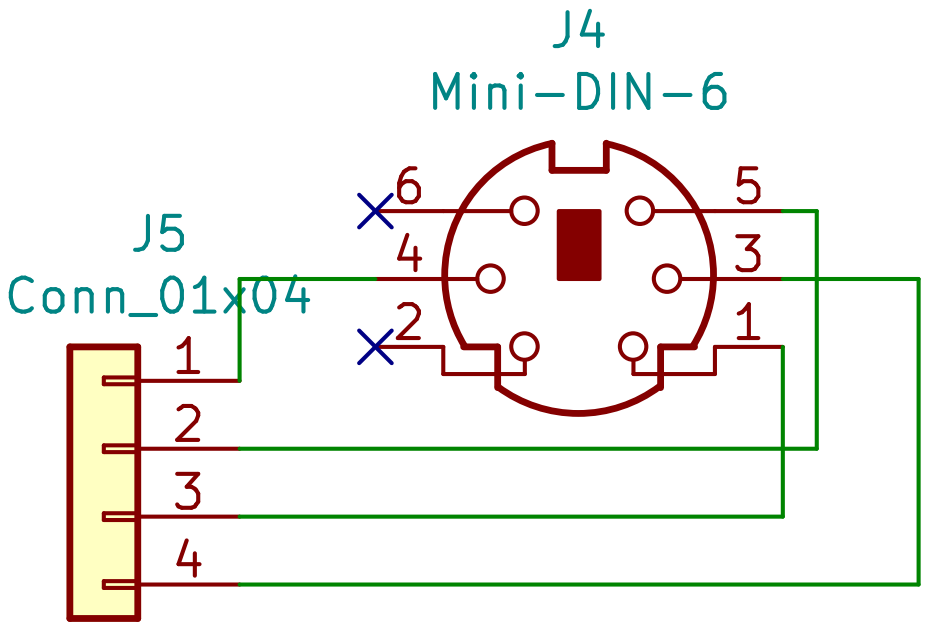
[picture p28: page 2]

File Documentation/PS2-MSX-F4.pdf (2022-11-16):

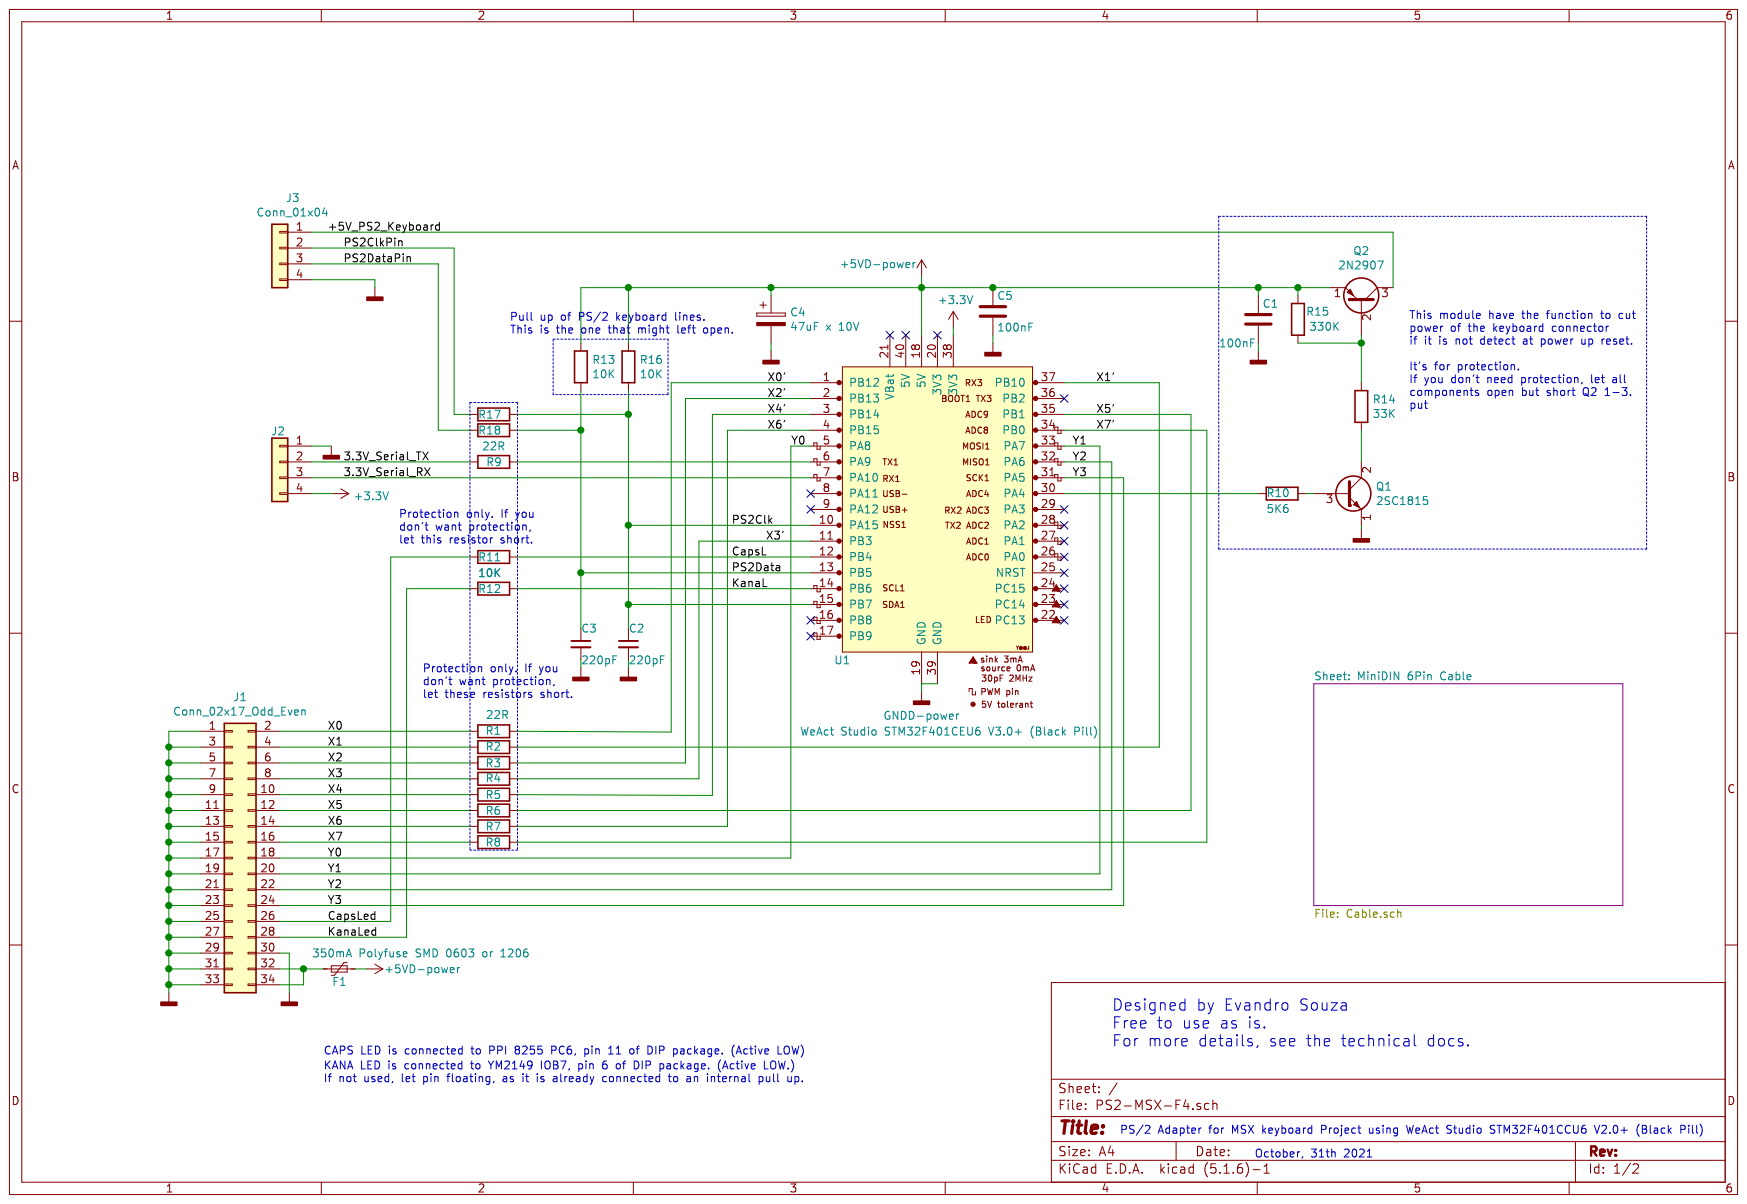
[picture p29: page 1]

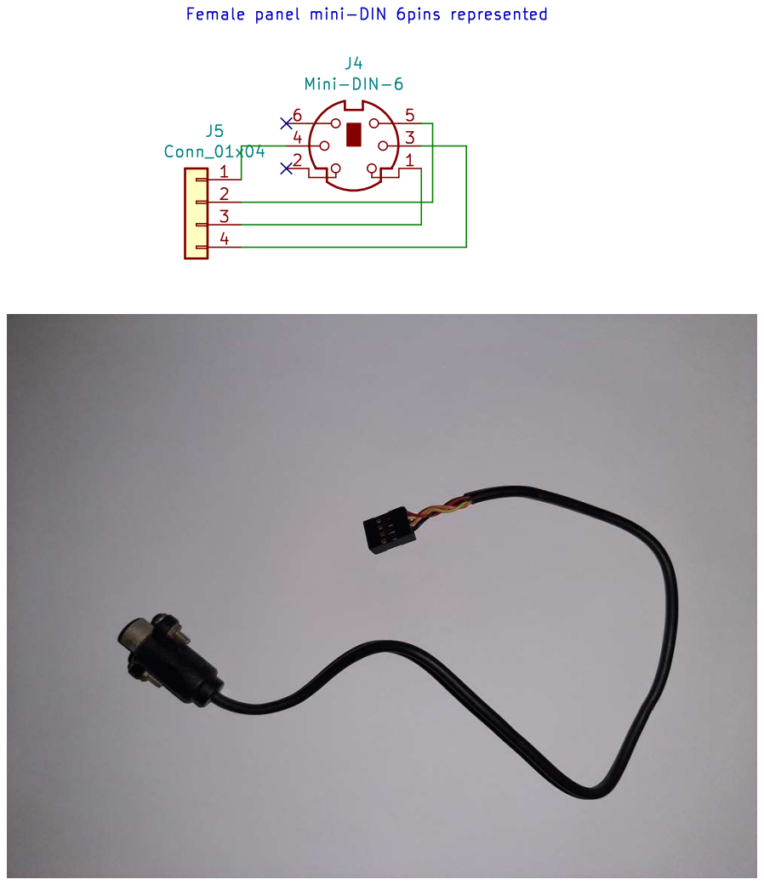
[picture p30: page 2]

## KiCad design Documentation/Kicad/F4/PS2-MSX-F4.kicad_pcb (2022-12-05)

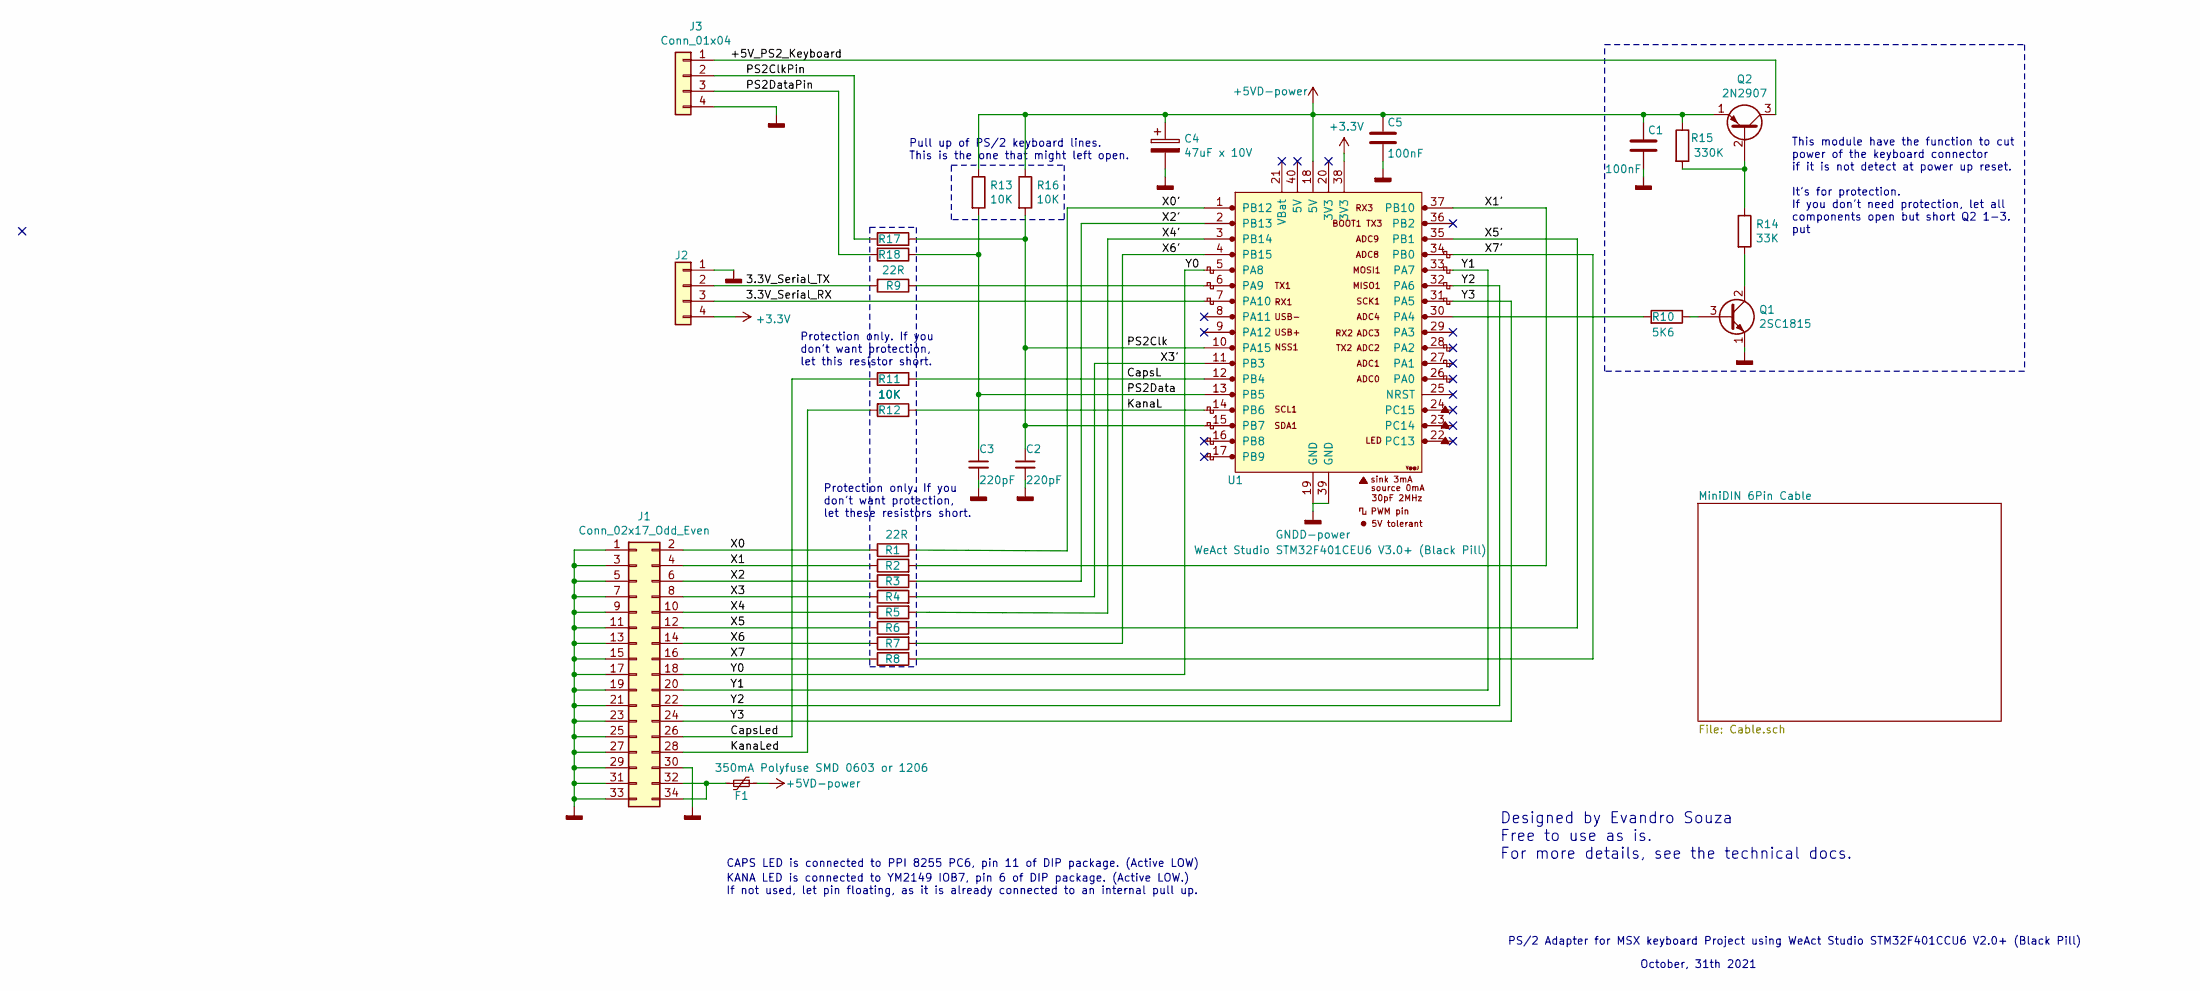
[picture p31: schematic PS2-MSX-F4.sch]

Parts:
C1, C5: 100nF; C_Disc_D4.3mm_W1.9mm_P5.00mm
C2, C3: 220pF; C_Disc_D4.3mm_W1.9mm_P5.00mm
C4: 47uF x 10V; CP_Radial_D5.0mm_P2.50mm
F1: 350mA Polyfuse SMD 0603 or 1206; Fuse_1206_0603_3216Metric_Pad1.42x1.75mm_HandSolder
J1: Conn_02x17_Odd_Even; PinHeader_2x17_P2.54mm_Vertical
J2: Conn_01x04; PinSocket_1x04_P2.54mm_Vertical
J3: Conn_01x04; PinHeader_1x04_P2.54mm_Vertical
Q1: 2SC1815; TO-92_Inline
Q2: 2N2907; TO-92_Inline
R1, R2, R3, R4, R5, R6, R7, R8, R9, R17, R18: 22R; R_Axial_DIN0204_L3.6mm_D1.6mm_P7.62mm_Horizontal
R10: 5K6; R_Axial_DIN0204_L3.6mm_D1.6mm_P7.62mm_Horizontal
R11, R12, R13, R16: 10K; R_Axial_DIN0204_L3.6mm_D1.6mm_P7.62mm_Horizontal
R14: 33K; R_Axial_DIN0204_L3.6mm_D1.6mm_P7.62mm_Horizontal
R15: 330K; R_Axial_DIN0204_L3.6mm_D1.6mm_P7.62mm_Horizontal
U1: WeAct Studio STM32F401CEU6 V3.0+ (Black Pill); BlackPill-minif4_board-1

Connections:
+3V3: J2.4, U1.38 (3V3)
+5VD: C1.1, C4.1, C5.1, F1.1, Q2.1 (E), R13.1, R15.1, R16.1, U1.18 (5V)
/3.3V_Serial_RX: J2.3, U1.7 (PA10)
/3.3V_Serial_TX: J2.2, R9.2
/+5V_PS2_Keyboard: J3.1, Q2.3 (C)
/CapsL: R11.1, U1.12 (PB4)
/CapsLed: J1.26, R11.2
/KanaL: R12.1, U1.14 (PB6)
/KanaLed: J1.28, R12.2
/PS2Clk: C2.1, R16.2, R17.1, U1.10 (PA15), U1.15 (PB7)
/PS2ClkPin: J3.2, R17.2
/PS2Data: C3.1, R13.2, R18.1, U1.13 (PB5)
/PS2DataPin: J3.3, R18.2
/X0: J1.2, R1.1
/X0': R1.2, U1.1 (PB12)
/X1: J1.4, R2.1
/X1': R2.2, U1.37 (PB10)
/X2: J1.6, R3.1
/X2': R3.2, U1.2 (PB13)
/X3: J1.8, R4.1
/X3': R4.2, U1.11 (PB3)
/X4: J1.10, R5.1
/X4': R5.2, U1.3 (PB14)
/X5: J1.12, R6.1
/X5': R6.2, U1.35 (PB1)
/X6: J1.14, R7.1
/X6': R7.2, U1.4 (PB15)
/X7: J1.16, R8.1
/X7': R8.2, U1.34 (PB0)
/Y0: J1.18, U1.5 (PA8)
/Y1: J1.20, U1.33 (PA7)
/Y2: J1.22, U1.32 (PA6)
/Y3: J1.24, U1.31 (PA5)
GNDD: C1.2, C2.2, C3.2, C4.2, C5.2, J1.1, J1.3, J1.5, J1.7, J1.9, J1.11, J1.13, J1.15, J1.17, J1.19, J1.21, J1.23, J1.25, J1.27, J1.29, J1.30, J1.31, J1.33, J2.1, J3.4, Q1.1 (E), U1.19 (GND), U1.39 (GND)
unnamed: F1.2, J1.32, J1.34
unnamed: Q1.2 (C), R14.2
unnamed: Q1.3 (B), R10.1
unnamed: Q2.2 (B), R14.1, R15.2
unnamed: R9.1, U1.6 (PA9)
unnamed: R10.2, U1.30 (PA4)

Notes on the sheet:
KANA LED is connected to YM2149 IOB7, pin 6 of DIP package. (Active LOW.) If not used, let pin floating, as it is already connected to an internal pull up.
CAPS LED is connected to PPI 8255 PC6, pin 11 of DIP package. (Active LOW)
October, 31th 2021
PS/2 Adapter for MSX keyboard Project using WeAct Studio STM32F401CCU6 V2.0+ (Black Pill)
Designed by Evandro Souza Free to use as is. For more details, see the technical docs.
Protection only. If you don't want protection, let these resistors short.
Pull up of PS/2 keyboard lines. This is the one that might left open.
Protection only. If you don't want protection, let this resistor short.
This module have the function to cut power of the keyboard connector if it is not detect at power up reset. It's for protection. If you don't need protection, let all components open but short Q2 1-3. put

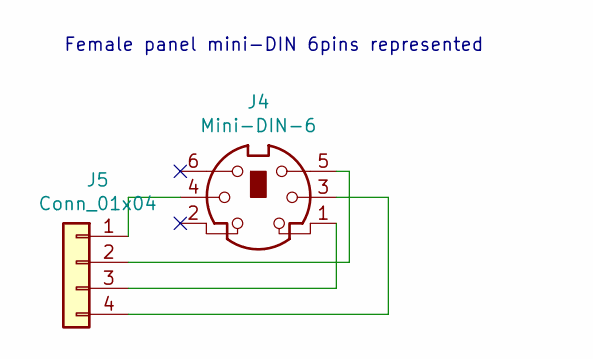
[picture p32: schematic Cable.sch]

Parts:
J4: Mini-DIN-6
J5: Conn_01x04

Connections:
unnamed: J4.1, J5.3
unnamed: J4.3, J5.4
unnamed: J4.4, J5.1
unnamed: J4.5, J5.2

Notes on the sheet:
Female panel mini-DIN 6pins represented

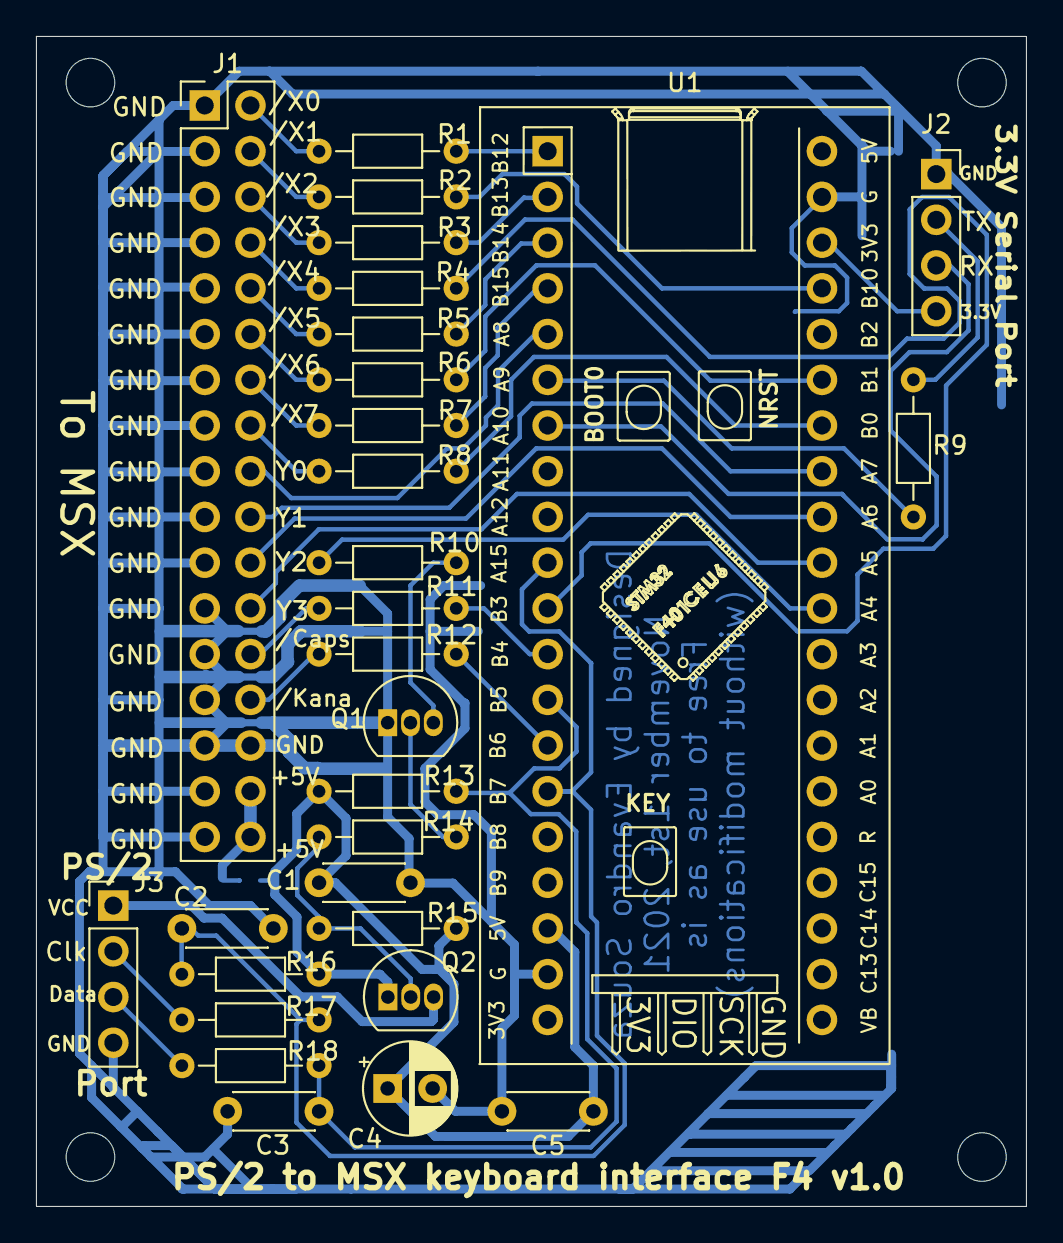
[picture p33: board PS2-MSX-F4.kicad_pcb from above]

Board: 2 copper layers, 55.0 x 65.0 mm, 30 parts (1 on the bottom side), 40 nets.

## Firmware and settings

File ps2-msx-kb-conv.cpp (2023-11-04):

/** @addtogroup 01 Manager_group Main
 *
 * @ingroup Main_design_definitions
 *
 * @file ps2-msx-kb-conv.cpp Main code. Created as Bare Metal (no OS needed).
 *
 * @brief <b>Main code. Created as Bare Metal (no OS needed).</b>
 *
 * @version 1.0.0
 *
 * @author @htmlonly &copy; @endhtmlonly 2022
 * Evandro Souza <evandro.r.souza@gmail.com>
 *
 * @date 25 September 2022
 *
 * This is the main file of PS/2 to MSX Keyboard Converter with supports
 * the STM32F4 and STM32F1 series of ARM Cortex Microcontrollers by ST Microelectronics.
 *
 * LGPL License Terms ref lgpl_license
 */

/*
 * This file is part of the PS/2 to MSX Keyboard converter enviroment:
 * PS/2 to MSX keyboard Converter and MSX Keyboard Subsystem Emulator
 * designs, based on libopencm3 project.
 *
 * Copyright (C) 2022 Evandro Souza <evandro.r.souza@gmail.com>
 *
 * This original SW is compiled to a Sharp/Epcom MSX HB-8000 and a brazilian ABNT2 PS/2 keyboard (ID=275)
 * But it is possible to update the table sending a Intel Hex File through serial or USB
 *
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
 * You should have received a copy of the GNU Lesser General Public License
 * along with this library.  If not, see <http://www.gnu.org/licenses/>.
 */

//Use Tab width=2

#include <libopencm3/stm32/rcc.h>
#include <libopencm3/cm3/systick.h>
#include <libopencm3/stm32/gpio.h>
#include <libopencm3/stm32/timer.h>
#include <libopencm3/stm32/iwdg.h>
#include <libopencm3/stm32/usart.h>

#include "system.h"
#include "sys_timer.h"
#include "serial.h"
#include "hr_timer.h"
#include "ps2handl.h"
#include "msxmap.h"
#include "SpecialFaultHandlers.h"
#include "serial_no.h"
#include "dbasemgt.h"
#if USE_USB == true
#include "cdcacm.h"
#endif  //#if USE_USB == true
#include "version.h"

//#define DO_PRAGMA(x) _Pragma (#x)
//#define TODO(x) DO_PRAGMA(message (#x))

#define  DELAY_JHONSON  6

//Variáveis globais
extern uint32_t systicks;                         //Declared on sys_timer.cpp
extern bool     mount_scancode_OK;                //Declared on ps2handl.c
extern bool     ps2_keyb_detected;                //Declared on ps2handl.c
extern bool     ps2numlockstate;                  //Declared on ps2handl.c
extern bool     command_running, ps2int_RX_bit_idx;//Declared on ps2handl.c
extern bool     caps_state, kana_state;           //Declared on ps2handl.c
extern bool     caps_former, kana_former;         //Declared on ps2handl.c
extern bool     update_ps2_leds;                  //Declared on msxmap.cpp
extern bool     compatible_database;              //Declared on msxmap.cpp
extern uint8_t  scancode[4];                      //Declared on msxmap.cpp
extern uint32_t formerscancode;                   //Declared on msxmap.cpp
extern bool     do_next_keep_alive;               //Declared on msxmap.cpp
extern uint8_t  serial_no[LEN_SERIAL_No + 1];     //Declared on serial_no.c
#if USE_USB == true
extern int      usb_configured;                   //Declared on cdcacm.c
int             usb_configured_prev;
#endif  //#if USE_USB === true


//Prototype area
void end_of_code(uint32_t*);

int main(void)
{
  uint32_t reset_org;
  end_of_code(&reset_org);

#if MCU == STM32F103
  //Blue Pill
  rcc_clock_setup_pll(&rcc_hse_configs[RCC_CLOCK_HSE8_72MHZ]);

  rcc_periph_clock_enable(RCC_AFIO); //Have to clock AFIO to use PA15 and PB4 freed by gpio remap below

  // Bits 9:8 TIM2_REMAP[1:0]: TIM2 remapping - 01: Partial remap (CH1/ETR/PA15, CH2/PB3, CH3/PA2, CH4/PA3)
  gpio_primary_remap(AFIO_MAPR_TIM2_REMAP_PARTIAL_REMAP1, 0);

  // Full Serial Wire JTAG capability without JNTRST
  //gpio_primary_remap(AFIO_MAPR_SWJ_CFG_FULL_SWJ_NO_JNTRST, 0);

  // Disable JTAG, enable SWD. This frees up GPIO PA15 (JTDI), PB3 (JTDO / TRACESWO) and PB4 (NJTRST)
  // GPIO PA13 (SWDIO) and PA14 (SWCLK) are still used by STlink SWD.
  //I didn't be successful to get PB3 freeed, and I had to reengineered this new solution, like
  //do not use interrupts to CAPS and KANA LEDs, and, for example, I put them inside systicks task,
  //that I suppose it is a better solution.
  gpio_primary_remap(AFIO_MAPR_SWJ_CFG_JTAG_OFF_SW_ON, 0);
#endif  //#if MCU == STM32F103

#if MCU == STM32F401
  //WeAct miniF4 STM32F401CCU6 and up, V2.0 and up (Black Pill)
  rcc_clock_setup_pll(&rcc_hse_25mhz_3v3[RCC_CLOCK_3V3_84MHZ]);
#endif  //#if MCU == STM32F401

  rcc_periph_clock_enable(RCC_GPIOA);
  rcc_periph_clock_enable(RCC_GPIOB);
  rcc_periph_clock_enable(RCC_GPIOC);

  power_on_ps2_keyboard();

  //Debug & performance measurement
  general_debug_setup();

  //Minimize interferencies from unused pins left open
  put_pullups_on_non_used_pins();

  //Get Serial number based on unique microcontroller factory masked number
  serialno_read(serial_no);

  serial_setup();

#if USE_USB == true
  cdcacm_init();
  //Give some time to USB be enumerated and recognized by the OS and terminal app
  for (uint32_t i = 0; i < 0x4000000; i++) __asm__("nop");
#endif  //#if USE_USB == true

  con_send_string((uint8_t*)"\r\n\n\r\nPS/2 to MSX Keyboard Converter " FIRMWARE_VERSION);
  con_send_string((uint8_t*)"\r\nBased on " HARDWARE_BASE "\r\nSerial number ");
  con_send_string((uint8_t*)serial_no);
  con_send_string((uint8_t*)"\r\nFirmware built on ");
  con_send_string((uint8_t*)__DATE__);
  con_send_string((uint8_t*)" ");
  con_send_string((uint8_t*)__TIME__);
  con_send_string((uint8_t*)"\r\n\nThis boot was requested from ");


  uint8_t mnt_str[MNTSTR_SIZE];
  s_pascal_string pascal_string;
  // Compute, prepare and print user message about last reset.
  pascal_string_init(&pascal_string, mnt_str, MNTSTR_SIZE);

  if(reset_org & RCC_CSR_PINRSTF)
    string_append((uint8_t*)"NRST_pin", &pascal_string);
  if(reset_org & RCC_CSR_PORRSTF){
    if(pascal_string.str_len == 8)
      string_append((uint8_t*)" and PowerOn", &pascal_string);
    else
      string_append((uint8_t*)"Software", &pascal_string);}
  if(reset_org & RCC_CSR_SFTRSTF){
    if(pascal_string.str_len >= 8)
      string_append((uint8_t*)" and Software", &pascal_string);
    else
      string_append((uint8_t*)"Software", &pascal_string);}
  if(reset_org & RCC_CSR_IWDGRSTF){
    if(pascal_string.str_len >= 8)
      string_append((uint8_t*)" and IWDG", &pascal_string);
    else
      string_append((uint8_t*)"IWDG", &pascal_string);}
  if(reset_org & RCC_CSR_WWDGRSTF){
    if(pascal_string.str_len >= 8)
      string_append((uint8_t*)" and WWDG", &pascal_string);
    else
      string_append((uint8_t*)"WWDG", &pascal_string);}
  if(reset_org & RCC_CSR_LPWRRSTF){
    if(pascal_string.str_len >= 8)
      string_append((uint8_t*)" and Low-power", &pascal_string);
    else
      string_append((uint8_t*)"Low-power", &pascal_string);}
  con_send_string(pascal_string.data);
  //After send pascal_string.data to console, clear it.
  pascal_string.str_len = 0;
  pascal_string.data[0] = 0;

  con_send_string((uint8_t*)". Booting...");

  con_send_string((uint8_t*)"\r\n\r\nConfiguring:\r\n");

#if USE_USB == true
  if(usb_configured)
    con_send_string((uint8_t*)". USB has been enumerated => Console and UART are over USB;\r\n");
  else
    con_send_string((uint8_t*)". USB host not found => Using Console over UART;\r\n. USB not disabled\r\n");
#else //#if USE_USB == true
  con_send_string((uint8_t*)". Non USB version => Console is over UART.\r\n");
#endif  //#if USE_USB == true

#if USE_USB == true
  usb_configured_prev = usb_configured;
#endif  //#if USE_USB == true

  con_send_string((uint8_t*)". PS/2 Port powered up.\r\n");
  con_send_string((uint8_t*)". ARM System Timer;\r\n");

  systick_setup();
  
  con_send_string((uint8_t*)". Independent Watch Dog Timer;\r\n");

  // Turn on the Independent WatchDog Timer
  iwdg_set_period_ms(100);  // 3 x sys_timer
  iwdg_start();

  con_send_string((uint8_t*)". High resolution Timer;\r\n");

  // Now configure High Resolution Timer for PS/2 Clock interrupts (via CC) and micro second Delay
  tim_hr_setup(TIM_HR);

  con_send_string((uint8_t*)". PS/2 Port: Waiting up to 2.5s (75 ticks) with powered on keyboard\r\n");
  con_send_string((uint8_t*)"  to proceed BAT: |.....|\r  to proceed BAT: |");

  ps2_keyb_detect();

  con_send_string((uint8_t*)". Database with know-how to manage and interface PS/2 Keyboard to MSX:\r\n");
  //Check the Database version, get y_dummy, ps2numlockstate and enable_xon_xoff
  database_setup();

  con_send_string((uint8_t*)". 5V compatible pin ports and interrupts to interface to MSX.\r\n");

  msxmap object;
  object.msx_interface_setup();

  if (!compatible_database || !ps2_keyb_detected)
  {
    //Here it will allow update the Database Conversion, as the PS/2 keyboard was not detected
    //or Database is incompatible, so at this point, this module is not working as target planned.

    //No PS/2 keyboard, so power off the port.
    power_off_ps2_keyboard();

    //Init procedure to fillin MSXTABLE by receiving an INTEL HEX through USART1
    //Disables all interrupts but systicks and USART
    exti_disable_request(Y3_exti | Y2_exti | Y1_exti | Y0_exti);
    timer_disable_irq(TIM_HR, TIM_DIER_CC1IE | TIM_DIER_UIE);
    exti_disable_request(PS2_CLK_I_EXTI);

    //Read the MSX Database Table Intel Hex by serial (or USB when available) and flashes 2560 bytes, from 0x08007600 to 0x08007FFF
    //Up to 3 databases can be put in flash without need to erase. It is automatically managed.
    flash_rw();

    //Halt here.
    for(;;);
  }

  con_send_string((uint8_t*)"\r\nBoot complete. Be welcome!\r\n");

  //Test keyboard leds for humans, using Jhonson Counter mode.
  uint32_t systicks_base = systicks;
  ps2_update_leds(false, false, false);
  while (systicks < (systicks_base + 1 * DELAY_JHONSON)) __asm("nop");

  ps2_update_leds(true, false, false);
  while (systicks < (systicks_base + 2 * DELAY_JHONSON)) __asm("nop");

  ps2_update_leds(true, true, false);
  while (systicks < (systicks_base + 3 * DELAY_JHONSON)) __asm("nop");

  ps2_update_leds(true, true, true);
  while (systicks < (systicks_base + 4 * DELAY_JHONSON)) __asm("nop");

  ps2_update_leds(false, true, true);
  while (systicks < (systicks_base + 5 * DELAY_JHONSON)) __asm("nop");

  ps2_update_leds(false, false, true);
  while (systicks < (systicks_base + 6 * DELAY_JHONSON)) __asm("nop");

  ps2_update_leds(false, false, false);
  while (systicks < (systicks_base + 7 * DELAY_JHONSON)) __asm("nop");


  /*********************************************************************************************/
  /************************************** Main Loop ********************************************/
  /*********************************************************************************************/
  uint32_t* ptr_scancode = (uint32_t*)scancode;
  for(;;)
  {
    //The first functionality running in the main loop
    //New key processing:
    if (mount_scancode())
    {
      //At this point, we already have the assembled compound keys code, so
      //to avoid unnecessary processing at convert2msx, check if this last scancode
      //is different from the former one.
      if (*ptr_scancode != formerscancode)
      {
        //Serial message the keyboard change
        /*uint8_t mountstring[3];
        con_send_string((uint8_t*)"Bytes qty=");
        conv_uint8_to_2a_hex(scancode[0], mountstring);
        con_send_string(mountstring);
        con_send_string((uint8_t*)"; Scan code=");
        conv_uint8_to_2a_hex(scancode[1], mountstring);
        con_send_string(mountstring);
        con_send_string((uint8_t*)"; ");
        conv_uint8_to_2a_hex(scancode[2], mountstring);
        con_send_string(mountstring);
        con_send_string((uint8_t*)"; ");
        conv_uint8_to_2a_hex(scancode[3], mountstring);
        con_send_string(mountstring);
        con_send_string((uint8_t*)"\r\n"); */
        //Toggle led each PS/2 keyboard change (both new presses and releases).
        gpio_toggle(EMBEDDED_LED_PORT, EMBEDDED_LED_PIN); //Toggle led to indicate a scan code is beeing sent to convert2msx
        // Do the Database search and do the correct conversion to MSX
        msxmap objeto;
        objeto.convert2msx();
      } //if (scancode != formerscancode)
      //update former keystroke
      formerscancode = *ptr_scancode;
      //Now we can reset to prepair to do a new mount_scancode (Clear to read a new key press or release)
      *ptr_scancode = 0;
      mount_scancode_OK = false;
    } //if (mount_scancode())

    //If keyboard is not responding to commands, reinit it through reset
    if(!(systicks & (uint32_t)0x7F))
    { //each ~4s (128 * 1/30)
      if(do_next_keep_alive)  //when time comes up, do it just once
      {
        do_next_keep_alive = false;
        if(!keyboard_check_alive())
        {
          con_send_string((uint8_t*)"Keyboard is non responsive (KeepAlive): Reset requested by the system.\r\n");
          reset_requested();
        }
      }
    }
    else
      do_next_keep_alive = true;

    //The second functionality running in main loop: Update the keyboard leds
    if( !command_running  &&    //Only does led update when the previous one is concluded
        update_ps2_leds )
    {
      update_ps2_leds = false;
      caps_former = caps_state;
      kana_former = kana_state;
      ps2_update_leds(ps2numlockstate, !caps_state, !kana_state);
    } //if ( update_ps2_leds || (caps_state != caps_former) || (kana_state != kana_former) )

    //Keep RX serial buffer empty and echoes to output
    while(con_available_get_char())
    {
      uint8_t ch, m_str[4];

      ch = con_get_char();
      m_str[0] = ch;
      m_str[1] = 0;
      //Don't send X_OFF to avoid to lock the remote terminal, if it has X_ON/X_OFF enabled
      if(ch != X_OFF)
        con_send_string(m_str);
      else
        con_send_string((uint8_t*)"<X_OFF>");
    }

#if USE_USB == true
    if(!usb_configured_prev && usb_configured)
      con_send_string((uint8_t*)"\r\n\n. USB has been enumerated => Console and UART are now over USB!\r\n");
    usb_configured_prev = usb_configured;
#endif  //#if USE_USB = true

  } //for(;;)

  return 0; //Suppose never reach here
} //int main(void)

/// @brief Mark an end of code
///
/// @param *reset_org Pointer to get which was the cause of reset
void end_of_code(uint32_t*reset_org)
{
  //Query the reset cause
  *reset_org = RCC_CSR;
  RCC_CSR = RCC_CSR_RMVF;
} //int main(void)

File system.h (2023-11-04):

/** @defgroup 01 Manager_group Main
 *
 * @ingroup infrastructure_apis
 *
 * @file system.h System main definitions of the project.
 *
 * @brief <b>System main definitions of the project. Header file of all other headers.</b>
 *
 * @version 1.0.0
 *
 * @author @htmlonly &copy; @endhtmlonly 2022
 * Evandro Souza <evandro.r.souza@gmail.com>
 *
 * @date 25 September 2022
 *
 * This file has the main definitions about the design.
 * This original SW is compiled to a Sharp/Epcom MSX HB-8000 and a brazilian ABNT2 PS/2 keyboard (ID=275)
 * But it is possible to update the table sending a Intel Hex File through serial or USB
 *
 * It supports both the STM32F4 and STM32F1 series of ARM Cortex Microcontrollers
 * by ST Microelectronics.
 *
 * LGPL License Terms ref lgpl_license
 */

/*
 * This file is part of the PS/2 to MSX Keyboard converter enviroment:
 * PS/2 to MSX keyboard Converter and MSX Keyboard Subsystem Emulator
 * designs, based on libopencm3 project.
 *
 * Copyright (C) 2022 Evandro Souza <evandro.r.souza@gmail.com>
 *
 * This original SW is compiled to a Sharp/Epcom MSX HB-8000 and a brazilian ABNT2 PS/2 keyboard (ID=275)
 * But it is possible to update the table sending a Intel Hex File through serial or USB
 *
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
 * You should have received a copy of the GNU Lesser General Public License
 * along with this library.  If not, see <http://www.gnu.org/licenses/>.
 */



#ifdef __cplusplus
extern "C" {
#endif

#ifndef T_SYSTEM_H
#define T_SYSTEM_H


#include <libopencm3/stm32/usart.h>
#include <libopencm3/stm32/timer.h>
#include <libopencm3/usb/usbd.h>
#include <libopencm3/usb/dwc/otg_fs.h>

/* Microcontroller STM32F103 or STM32F401 */
#define STM32F103                 0x410     //Blue Pill
#define STM32F401                 0x423     //WeAct Studio MiniF4 Black Pill

#define MCU                       STM32F401


// Place to get the microcontroller unique id to compute serial number
#ifndef DESIG_UNIQ_ID_BASE
#if MCU == STM32F103
#define DESIG_UNIQ_ID_BASE        0x1FFFF7E8;
#define LEN_SERIAL_No             8
#endif  //#if MCU == STM32F103
#if MCU == STM32F401
#define DESIG_UNIQ_ID_BASE        0x1FFF7A10;
#define LEN_SERIAL_No             12
#endif  //#if MCU == STM32F401
#endif  //#ifndef DESIG_UNIQ_ID_BASE


/* Database allocation in flash */
#define DB_NUM_COLS               8
#define N_DATABASE_REGISTERS      320
#define DATABASE_SIZE             N_DATABASE_REGISTERS * DB_NUM_COLS

#if MCU == STM32F103
#define NUM_DATABASE_IMG          2
//Address of Base of flash page, used to put various Databases without need of erase each time
//update process is done.
#define FLASH_BASE_ADD            0x08000000
#define INITIAL_DATABASE          0x08007600  //Place to put the initial (compilation time) database
#define DATABASE_BASE_ADD         0x08006C00  //This address marks the beggining of page 27
#define DATABASE_BASE_PAGE        27
#define DATABASE_TOP_ADDR         0x08007FFF  //STM32F103C6T6 (32K Flash 10K RAM)
#define DATABASE_TOP_PAGE         31
#define FLASH_PAGE_SIZE           0x400       //1K in STM32F103
#endif  //#if MCU == STM32F103

#if MCU == STM32F401
#define NUM_DATABASE_IMG          6           //to fit in a 16k window
//Address of Base of flash page, used to put various Databases without need of erase each time
//update process is done. In STM32F4CCU6, the Database remains on the following flash address,
//with an amount of 16K (Flash Sector 3: 0x800C000 to 0x800FFFF)
#define INITIAL_DATABASE          0x0800F600  //SECTOR 3 - Place to put the initial (compilation time) database
#define FLASH_SECTOR3_BASE        0x0800C000
#define FLASH_SECTOR3_TOP         0x0800FFFF
#define FLASH_SECTOR3_NUMBER      3
#endif  //#if MCU == STM32F401


/* High Resolution Timer definitions */
#define TIM_HR                    TIM2        //Here we define which timer we will use for hrtimer
#if TIM_HR == TIM2
#define RCC_TIM_HR                RCC_TIM2
#define RST_TIM_HR                RST_TIM2
#define NVIC_TIM_HR_IRQ           NVIC_TIM2_IRQ
#define ISR_TIM_HR                void tim2_isr(void)
#endif  //#if TIM_HR_TIMER == TIM2


/* Interrupt priority definitions. From 0 to 15. Low numbers are high priority. */
/** Interrupt priority definitions.
 *
 * From 0 to 15. Low numbers are high priority.
@{*/
#define IRQ_PRI_Y_SCAN            (1 << 4)    //Colunm rows from 8255 (MSX)
#define IRQ_PRI_TIM_HR            (2 << 4)
#define IRQ_PRI_EXT15             (2 << 4)    //Keyboard, while int above is not working
#define IRQ_PRI_SYSTICK           (3 << 4)
#define IRQ_PRI_USB               (4 << 4)
#define IRQ_PRI_USART             (5 << 4)
#define IRQ_PRI_USART_DMA         (5 << 4)
/**@}*/


/* General definitions about timings */
/** General definitions about timings
 *
 * Timings used by systick and timeout of user input in user entry of Database update
@{*/
#define FREQ_INT_SYSTICK          30
#define MAX_TIMEOUT2RX_INTEL_HEX  11 * FREQ_INT_SYSTICK
#define MAX_TIMEOUT2AMPERSAND     6  * FREQ_INT_SYSTICK
/**@}*/


/* USB related definitions */

/* Define the usage of USB */
/** Define the usage of USB 
 * 
 * 
 */
#define USE_USB                   true      //Here you can change the USB support in M4 family.

#define CDC_ONLY_ON_USB           false     // If we are providing serial interfaces only => True

#if (MCU == STM32F103) && (USE_USB == true) //***** DO NOT CHANGE IT! In PS/2 keyboard Interface for MSX design blue pill DO NOT have sufficient hardware resouces (5V tolerant pins and Flash room) to support USB and basic target functionality.
#undef  USE_USB                             //***** DO NOT CHANGE IT! In PS/2 keyboard Interface for MSX design blue pill DO NOT have sufficient hardware resouces (5V tolerant pins and Flash room) to support USB and basic target functionality.
#define USE_USB                   false     //***** DO NOT CHANGE IT! In PS/2 keyboard Interface for MSX design blue pill DO NOT have sufficient hardware resouces (5V tolerant pins and Flash room) to support USB and basic target functionality.
#endif  //##if (MCU == STM32F103) && (USE_USB == true)
#if USE_USB == true
#if MCU == STM32F103
#define USB_DRIVER                st_usbfs_v1_usb_driver
#define USB_ISR                   void usb_lp_can_rx0_isr(void)
#define USB_NVIC                  NVIC_USB_LP_CAN_RX0_IRQ
#define USB_RCC_OTGFS             RCC_OTGFS
#endif  //#if MCU == STM32F103C8
#if MCU == STM32F401
#define USB_DRIVER                otgfs_usb_driver
#define USB_ISR                   void otg_fs_isr(void)
#define USB_NVIC                  NVIC_OTG_FS_IRQ
#define USB_RCC_OTGFS             RCC_OTGFS
#define USB_RCC_CRC               RCC_CRC
#endif  //#if MCU == STM32F401CC
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

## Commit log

2022-05-24 PS/2 to MSX keyboard adapter with USB Console
    USB is "at working" status, to leave the need of a serial adapter to upload the database.
    This is a bare metal design adapter based on STM32F401Mini to attach a PS/2 keyboard to a MSX [or other computers that use a up to 15 (input) x 8 (reading) matrix] with 4 bit BCD input. It has expand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
    This unit has a highly configurable capability, as it has an user updateable database, without need to recompile and upload a new code, to translate from PC keyboard to MSX.
2022-05-24 Update README.md
    STM32F401 with USB console based PS/2 Keyboard adapter for 15x8 matrix(BCD input - 8 bits "Low active" output) , mainly for use in MSX computers.
2022-05-27 README.md update
    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
2022-09-11 PS/2 to MSX keyboard adapter with USB Console
    USB is implemented to be used a console, in aim to leave the need of a serial adapter to upload the database.
    USB is available as DFU (Device Softwqre Update), so you will only need a USB C cable => the same cable used in nowadays mobile phones.
    This is a bare metal design adapter based on Blue Pill or Black Pill F401Mini to attach a PS/2 keyboard to a MSX [or other computers that use a up to 15 (input) x 8 (reading) matrix] with 4 bit BCD i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
    This unit has a highly configurable capability, as it has an user updateable database, without need to recompile and upload a new firmwware, t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
2022-09-25 PS/2 to MSX keyboard adapter with USB Console
    USB is implemented to be used as console, with the target to allow to upload the database through USB.
    This unit has a highly configurable capability, as it has an user updateable database, without need to recompile and upload a new firmwware, to trans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
2022-09-26 Presentation file in PDF
    PDF of a Power Point presentation file
2022-09-26 Presentatioin file
    Presentation file in PDF, from a Power Point one.
2022-09-28 Presentatioin file
    Presentation file in PDF, from a MS PowerPoint one. Small typing errors corrected.
2022-09-29 Presentation file
    Presentation file in PDF, from a MS PowerPoint one.
2022-10-03 Emglish PDF Presentation file
    English presentation file in PDF, from a MS PowerPoint one.
2022-10-04 English PDF Presentation file
    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
2022-10-04 Schematics and PCB Design
    Here are the Kicad schematics and PCB design, with all Gerber and drill files already extracted., and a zip to send to do a PCB maker to request for prices.
    Obs.: Kicad version is 5.99.
    [Cable.sch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]
2022-10-05 Kicad schematic and PCB files
    Upload Kicad schematic and PCB files
    [Cable.sch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]
2022-10-05 Schematic files in pdf format
2022-11-16 R10 valye update
    NPN base resistor update. Valid to PS/2 keyboard supply current up to 50mA.
2022-11-16 NPN base resistor update
    [PS2-MSX-F1.sch]
2022-11-16 BPB base resistor update
2022-11-24 R10 value update
    An old missing BOM update => R10: NPN base resistor had its value revised. Valid to PS/2 keyboard supply current up to 50mA.
2022-12-02 Documentation update
    Documentation update
    [Cable.sch, PS2-MSX-F1.kicad_pcb]
2022-12-02 Documentation update
    [Cable.sch, PS2-MSX-F4.sch]
2022-12-05 Kicad schematic and PCB files
    Kicad schematic and PCB files upload
    [PS2-MSX-F4-B_Cu.gbr, PS2-MSX-F4-B_Mask.gbr, PS2-MSX-F4-B_Paste.gbr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]
2022-12-10 File fixes
    Correction of line 586
    [system.h]
2022-12-22 Last minute clean up
    Documentation update including ARM GNU updated toolchain and last minute code cleanups.
2023-02-06 Upload the correct files
    Upload the correct files
    [system.h]
2023-04-30 Updated to (Build arm-12-mpacbti.34)
    Generated files to be uploaded, README.md and source code compiled with an Arm GNU Toolchain 12.2.1 20230214 (Arm GNU Toolchain 12.2.MPACBTI-Rel1 (Build arm-12-mpacbti.34)).
2023-11-04 Updated to (Arm GNU Toolchain 12.3.1 20230626)
    Generated files to be uploaded, README.md and source code compiled with an Arm GNU Toolchain 12.3.1 20230626 (Arm GNU Toolchain 12.3.Rel1 (Build arm-12.35)).
2023-11-04 Doxygen documentation related correction
    No logic corrections. Only Doxygen documentation related correction updates.
    [dbasemgt.c, msxmap.cpp, ps2-msx-kb-conv.cpp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]
2024-04-26 Updated to (Arm GNU Toolchain 13.2.Rel1 20231030)
    Generated files to be uploaded, README.md and source code compiled with an Arm GNU Toolchain 13.2.Rel1 20231030.
2024-09-21 Upload to support Arm GNU Toolchain 13.3.Rel1
    Uploaded files made with Arm GNU Toolchain 13.3.Rel1 Released: July 4, 2024
2024-09-21 Made with Arm GNU Toolchain 13.3.Rel1
    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
2025-04-20 Arm GNU Toolchain 14.2.Rel1 Updated
    Updated due to Arm GNU Toolchain 14.2.Rel1 Released: December 10, 2024
2025-04-20 Files updated due to Arm GNU Toolchain 14.2.Rel1
    Files updated due to Arm GNU Toolchain 14.2.Rel1 Released: December 10, 2024

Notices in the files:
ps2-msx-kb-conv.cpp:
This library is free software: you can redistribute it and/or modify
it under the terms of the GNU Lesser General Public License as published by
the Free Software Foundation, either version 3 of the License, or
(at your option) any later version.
